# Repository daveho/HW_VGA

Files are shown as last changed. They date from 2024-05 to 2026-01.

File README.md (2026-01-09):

# Hardware VGA text mode project

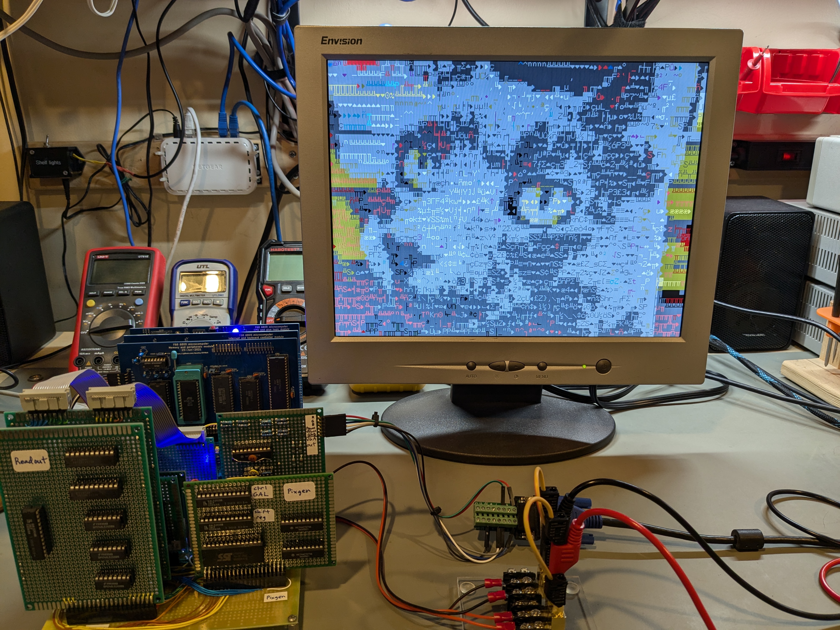
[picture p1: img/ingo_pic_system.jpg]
completed prototype showing cat picture (connected to DIY 8-bit computer)


This repository documents my (successful!) attempt to implement a VGA text mode using logic chips and GAL devices for my [8-bit computer project](https://github.com/daveho/DIY8bit).

In July 2024, the design reached the point where it was functional
as a hand-wired prototype.

In November 2025, an [FPGA implementation](https://github.com/daveho/FPGA_VGA)
of the display controller reached the point where it is fully
functional.

The project is documented as a series of youtube videos:

Video | Topic(s) | Supporting materials
----- | -------- |--------------------
[Episode 01](https://youtu.be/FBDaKUfpmKo) | Sync gen and pixel output | [Episode01](Episode01)
[Episode 02](https://youtu.be/wY-jgFELOBk) | VRAM | [Episode02](Episode02)
[Episode 03](https://youtu.be/mVbhe-eQTJc) | Readout | [Episode03](Episode03)
[Episode 04](https://youtu.be/JXyIJMKmy68) | Pixel generation | [Episode04](Episode04)
[Episode 05](https://youtu.be/PG1XWQCylTA) | FPGA implementation | [FPGA\_VGA repository](https://github.com/daveho/FPGA_VGA)

There are a few photos in the [Gallery](gallery.md).

This project was inspired by the [Wire Wrap Odyssey](https://wirewrapodyssey.com) project.

I'm using [Logisim Evolution](https://github.com/logisim-evolution/logisim-evolution) to simulate parts of the design before building the hardware.

I'm using [GALasm](https://github.com/daveho/GALasm) to compile the GAL logic equations into fuse maps. Note that even though this is hosted in my Github account, I didn't write it. (I fixed a bug and then posted the code on my Github since there didn't seem to be any existing version control repo for it.)

The [HardwareDesign](HardwareDesign) directory contains the most up-to-date hardware design. The schematics were created using (of course!) [KiCad](https://www.kicad.org/). There is a [PDF of the schematic](HardwareDesign/HW_VGA.pdf) which may or may not be up to date.

This is a work in progress! I don't make any guarantees about its usefulness or correctness. Feedback can be sent to <mailto:david.hovemeyer@gmail.com>.

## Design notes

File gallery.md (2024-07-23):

# Gallery

Here are some pictures:

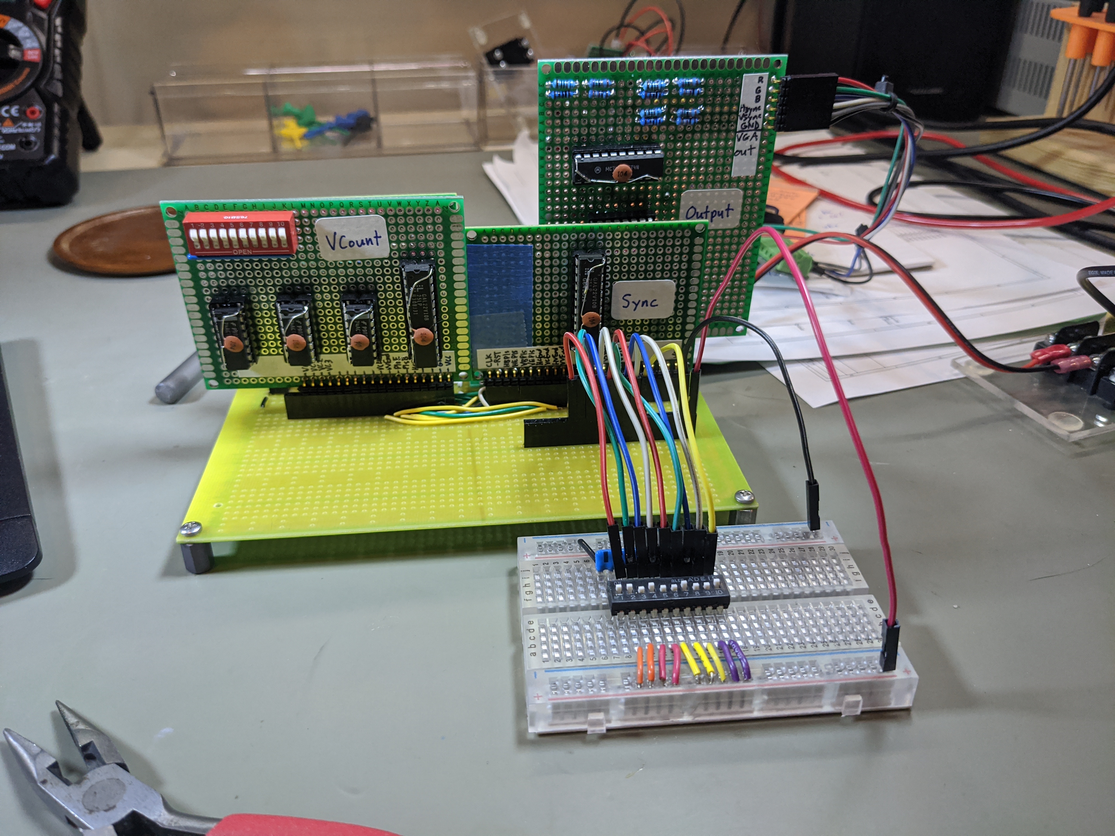
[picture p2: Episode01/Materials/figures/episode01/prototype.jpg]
photo of early prototype hardware


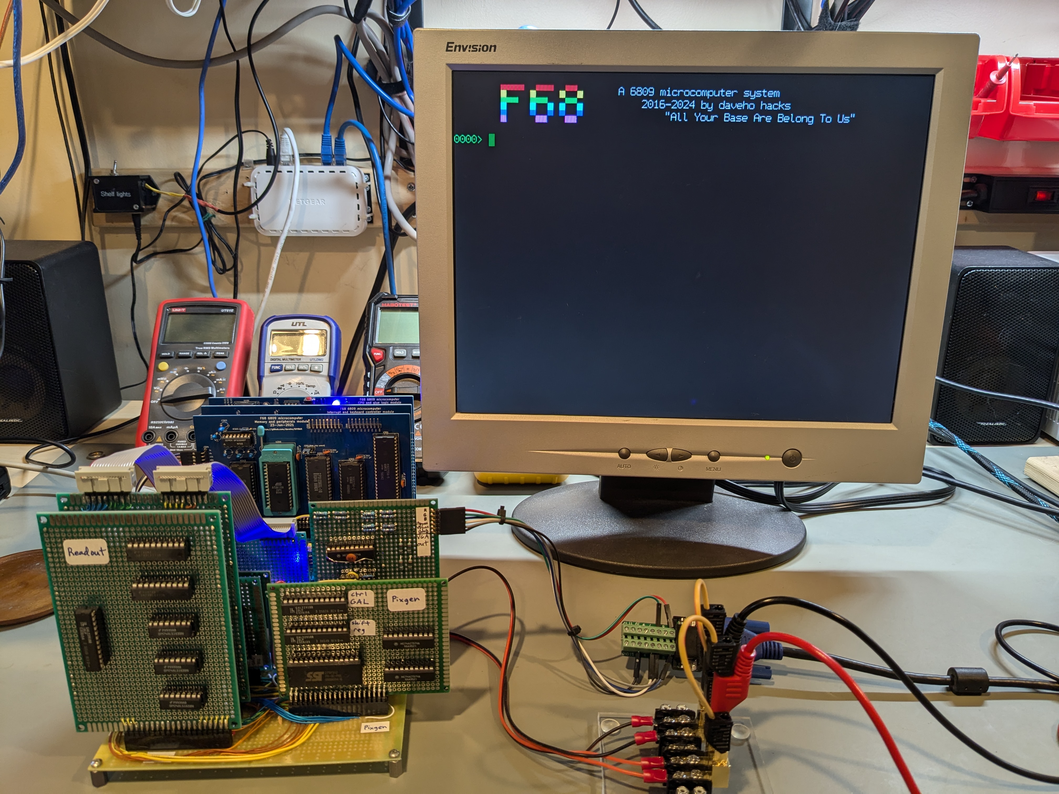
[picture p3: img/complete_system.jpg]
completed prototype (connected to DIY 8-bit computer)


completed prototype showing cat picture (connected to DIY 8-bit computer)

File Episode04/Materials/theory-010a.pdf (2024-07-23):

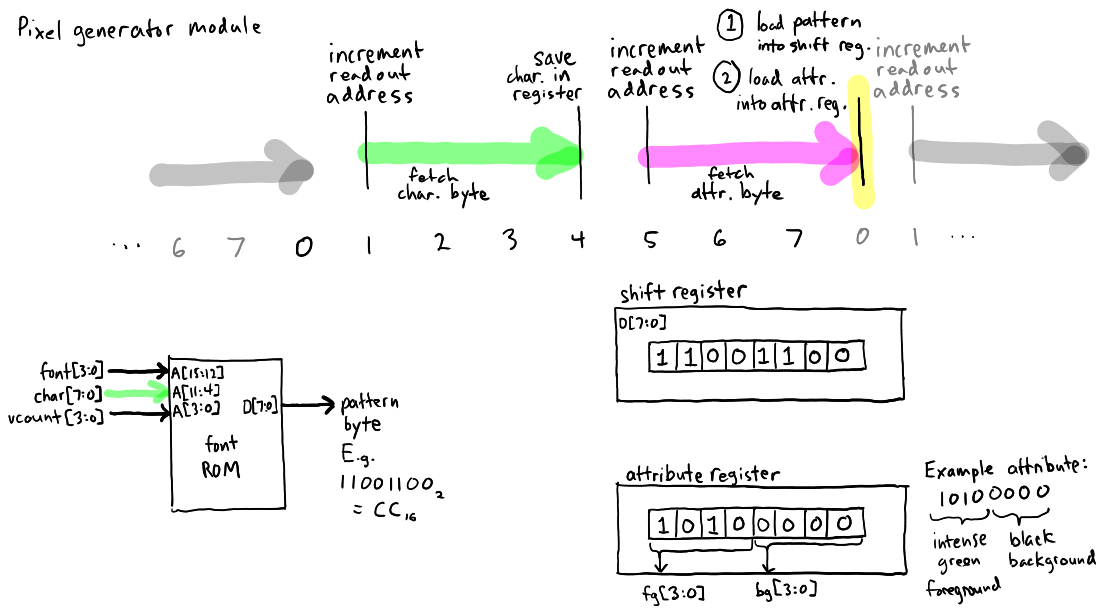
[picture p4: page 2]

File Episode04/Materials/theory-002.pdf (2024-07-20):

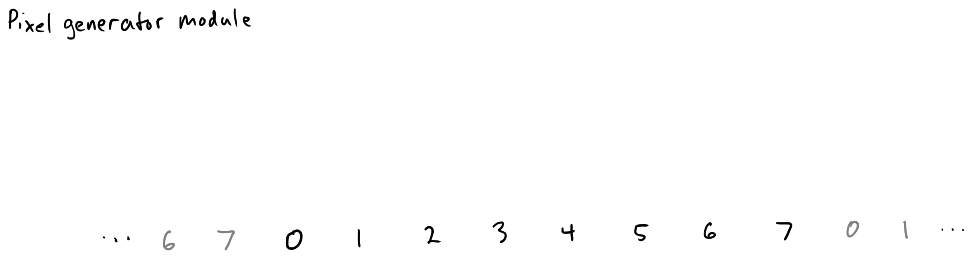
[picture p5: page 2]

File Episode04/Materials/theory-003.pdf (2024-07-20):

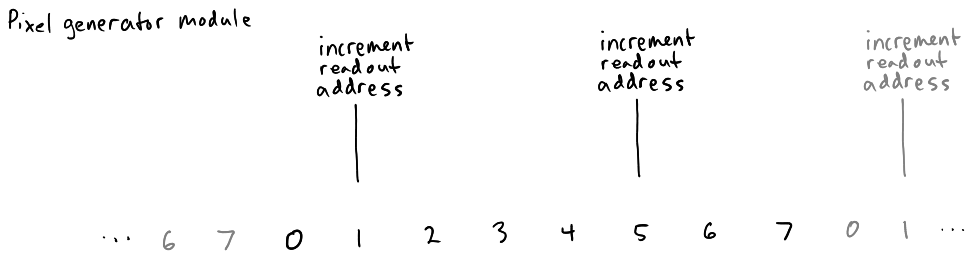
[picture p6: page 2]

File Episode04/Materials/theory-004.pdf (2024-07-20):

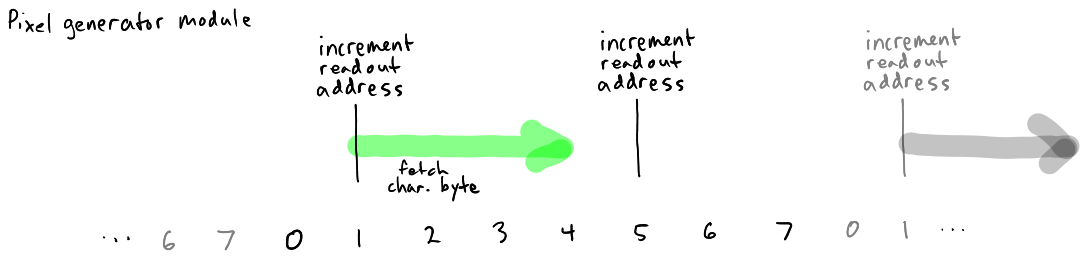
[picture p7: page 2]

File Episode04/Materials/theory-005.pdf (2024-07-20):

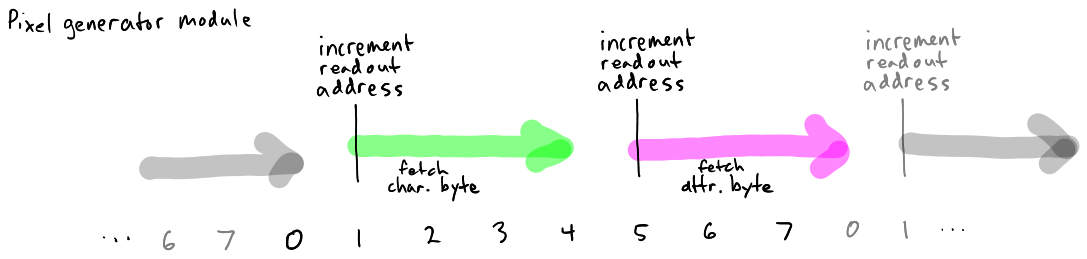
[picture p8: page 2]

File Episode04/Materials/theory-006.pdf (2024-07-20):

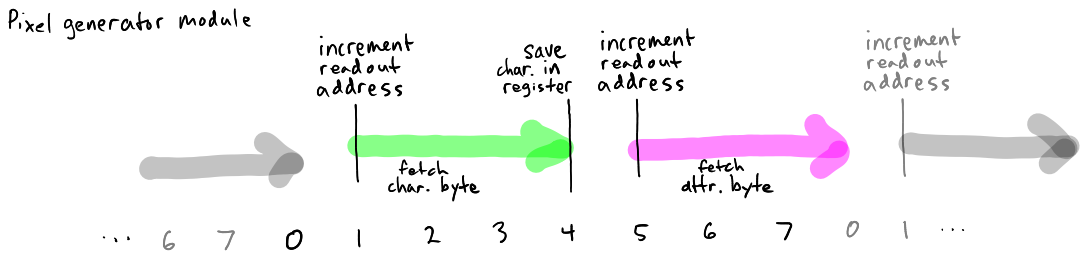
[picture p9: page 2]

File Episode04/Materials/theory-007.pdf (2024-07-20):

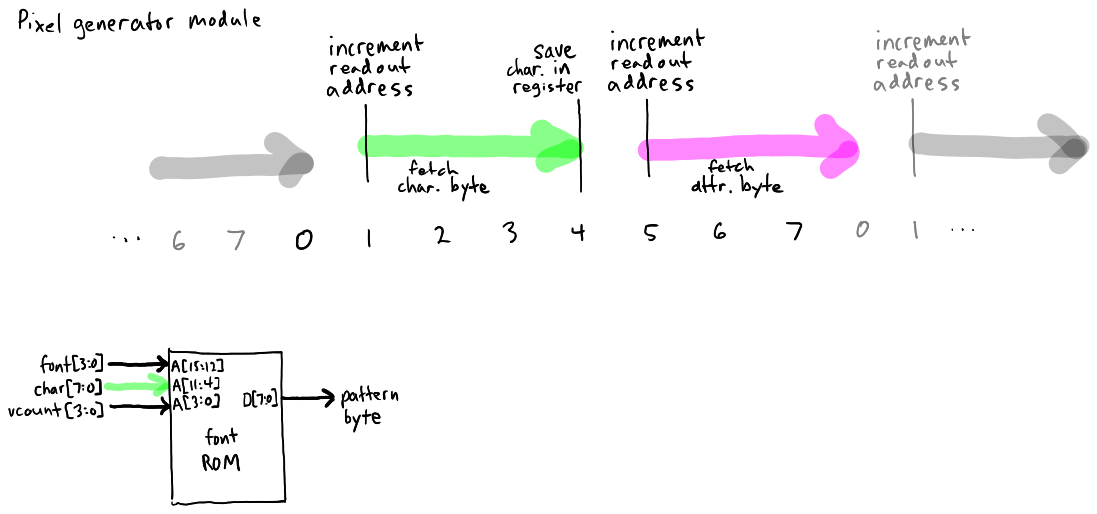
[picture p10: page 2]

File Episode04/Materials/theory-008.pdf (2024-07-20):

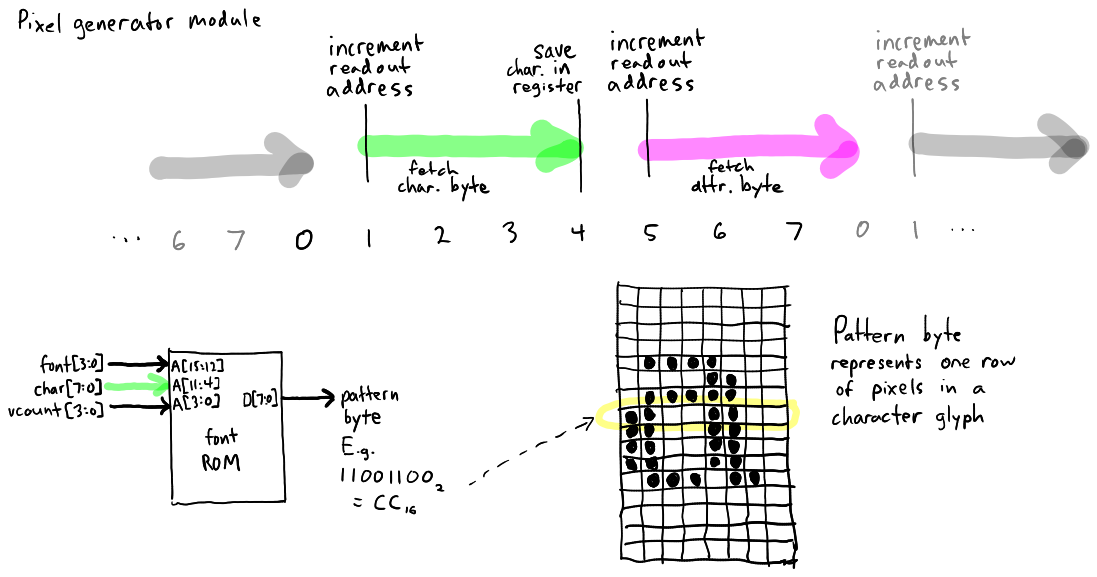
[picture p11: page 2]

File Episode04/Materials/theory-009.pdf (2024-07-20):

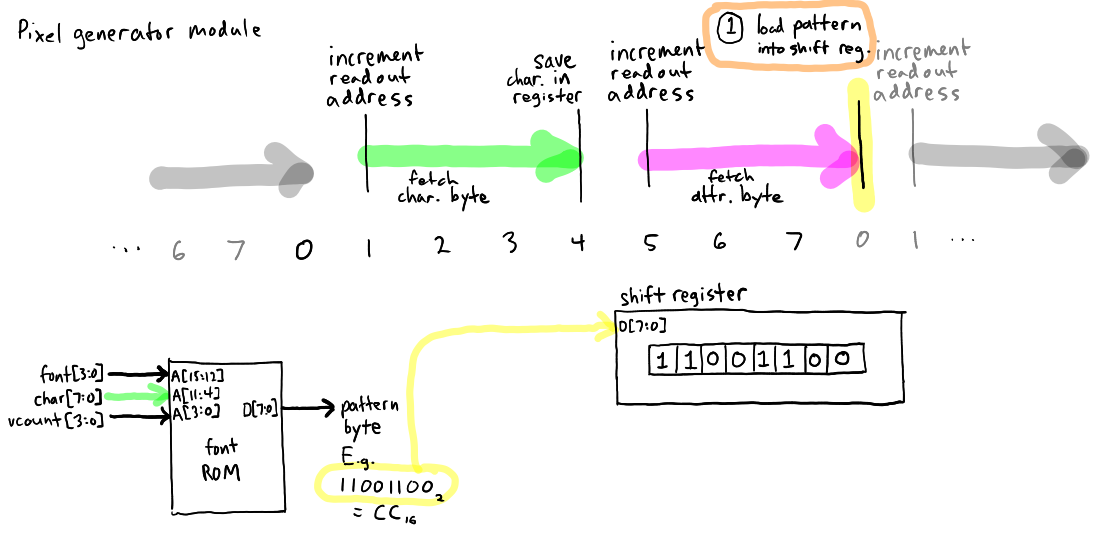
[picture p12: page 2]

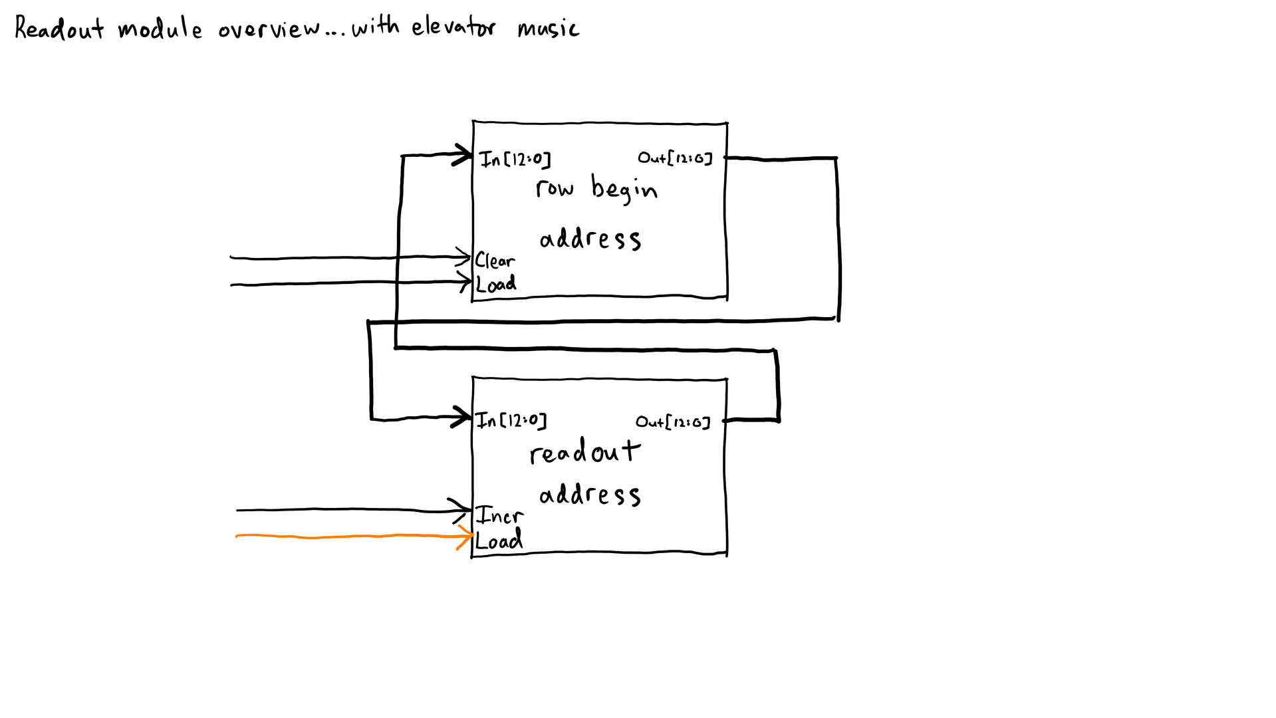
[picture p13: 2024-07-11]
Episode03/Materials/readout-overview-039.png

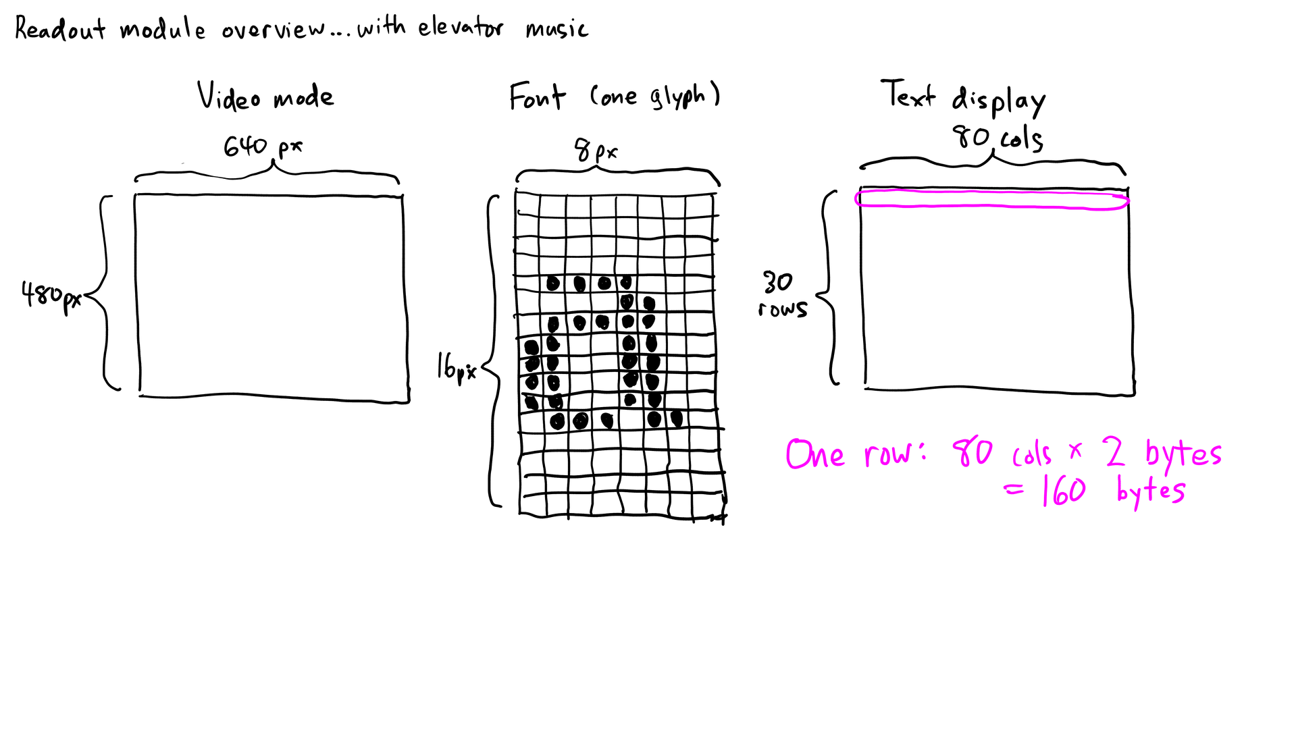
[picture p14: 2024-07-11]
Episode03/Materials/readout-overview-011.png

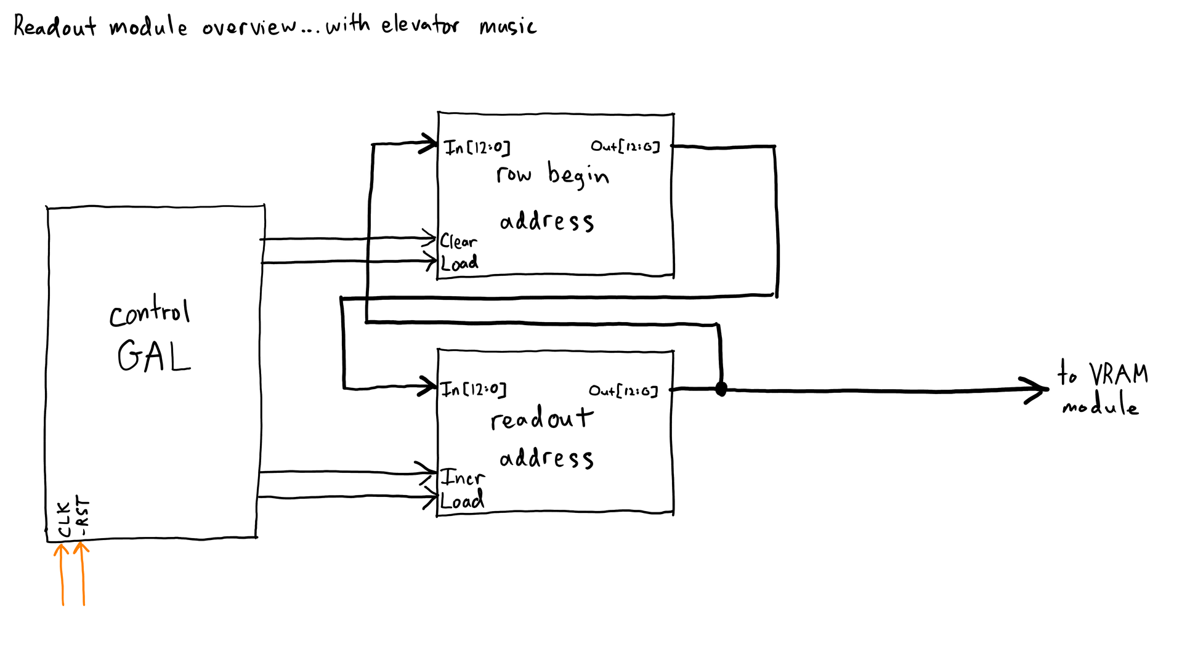
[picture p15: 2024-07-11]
Episode03/Materials/readout-overview-042.png

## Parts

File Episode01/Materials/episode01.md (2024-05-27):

---
title: "Episode 1"
aspectratio: 169
colorlinks: true
pandoc-beamer-block:
  - classes: [info]
  - classes: [alert]
    type: alert
header-includes:
  - \usepackage{graphbox}
  - \usepackage[export]{adjustbox}
  - \usepackage[absolute,overlay]{textpos}
  - \usecolortheme{orchid}
---

## 

::: { .absolute x=0.5in y=0.85in width=3in }



:::

## Hello! { .t }

New (but kind of not new) project!

## Hello! { .t }

New (but kind of not new) project!

Why no real videos for quite a while?

## Hello! { .t }

New (but kind of not new) project!

Why no real videos for quite a while?

* 8-bit computer project: initially lots of progress, lots of fun

## Hello! { .t }

New (but kind of not new) project!

Why no real videos for quite a while?

* 8-bit computer project: initially lots of progress, lots of fun
* Display controller: huge road block. Initial options:

## Hello! { .t }

New (but kind of not new) project!

Why no real videos for quite a while?

* 8-bit computer project: initially lots of progress, lots of fun
* Display controller: huge road block. Initial options:
  1. "Retro" display controller (e.g., TMS9918A)

::: { .absolute x=3in y=1.75in width=2.5in }

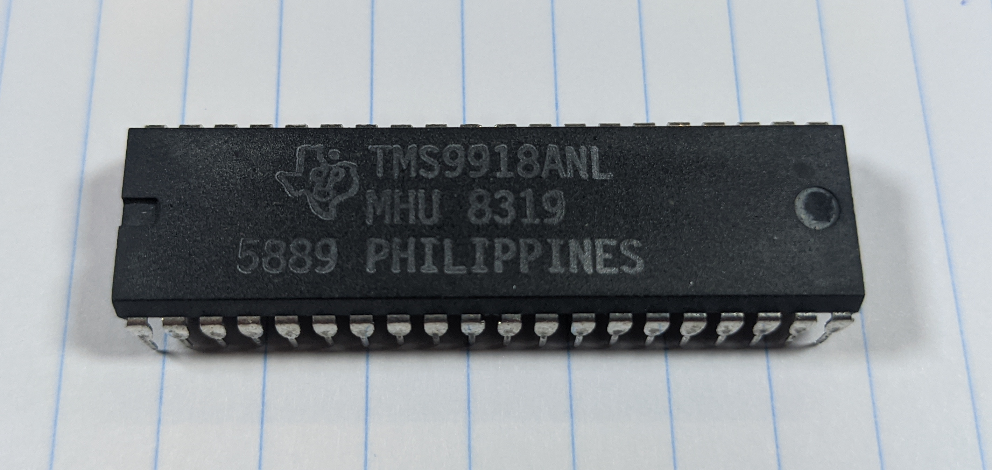
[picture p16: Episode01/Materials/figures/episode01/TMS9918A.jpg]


:::

## Hello! { .t }

New (but kind of not new) project!

Why no real videos for quite a while?

* 8-bit computer project: initially lots of progress, lots of fun
* Display controller: huge road block. Initial options:
  1. "Retro" display controller (e.g., TMS9918A)
  2. FPGA with custom design

::: { .absolute x=3in y=1.75in width=2.5in }

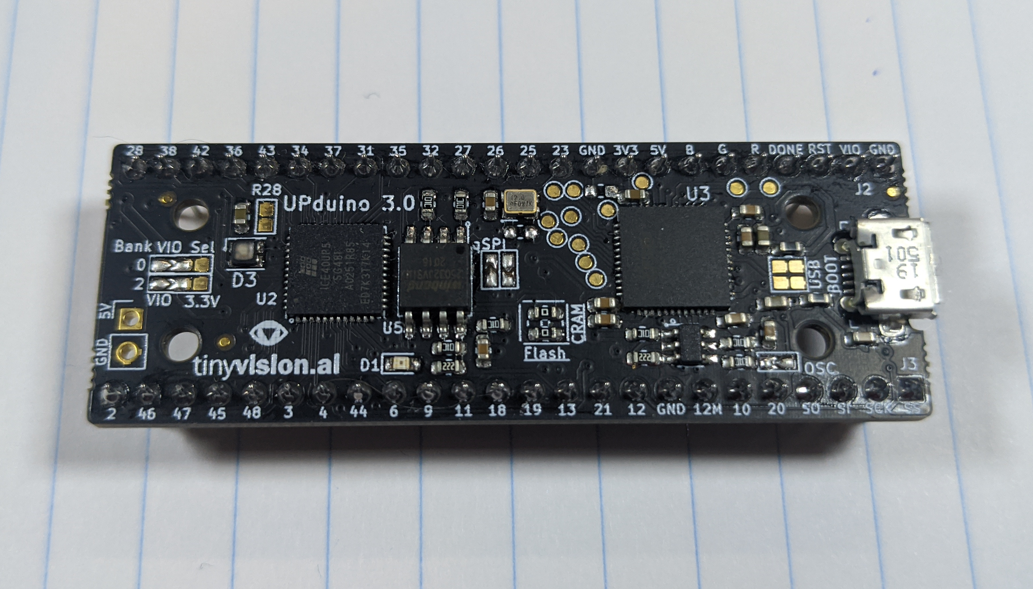
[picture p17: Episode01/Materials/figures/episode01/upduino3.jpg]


:::

## Hello! { .t }

New (but kind of not new) project!

Why no real videos for quite a while?

* 8-bit computer project: initially lots of progress, lots of fun
* Display controller: huge road block. Initial options:
  1. "Retro" display controller (e.g., TMS9918A)
  2. FPGA with custom design

Initially I thought option \#2 was best

## FPGAs are hard { .t }

Difficulties:

## FPGAs are hard { .t }

Difficulties:

* Hard to know what is going on inside the FPGA

## FPGAs are hard { .t }

Difficulties:

* Hard to know what is going on inside the FPGA
* Can't probe signals

## FPGAs are hard { .t }

Difficulties:

* Hard to know what is going on inside the FPGA
* Can't probe signals
* Need to use simulation and possibly formal verification

## FPGAs are hard { .t }

Difficulties:

* Hard to know what is going on inside the FPGA
* Can't probe signals
* Need to use simulation and possibly formal verification

My problem: I wasn't having fun!

## FPGAs are hard { .t }

Difficulties:

* Hard to know what is going on inside the FPGA
* Can't probe signals
* Need to use simulation and possibly formal verification

My problem: I wasn't having fun!

* I like building things

## FPGAs are hard { .t }

Difficulties:

* Hard to know what is going on inside the FPGA
* Can't probe signals
* Need to use simulation and possibly formal verification

My problem: I wasn't having fun!

* I like building things
* I like debugging circuits (using multimeter, oscilloscope, etc.)

## What about option \#1? { .t }

I did experiment with the TMS9918A with some success:

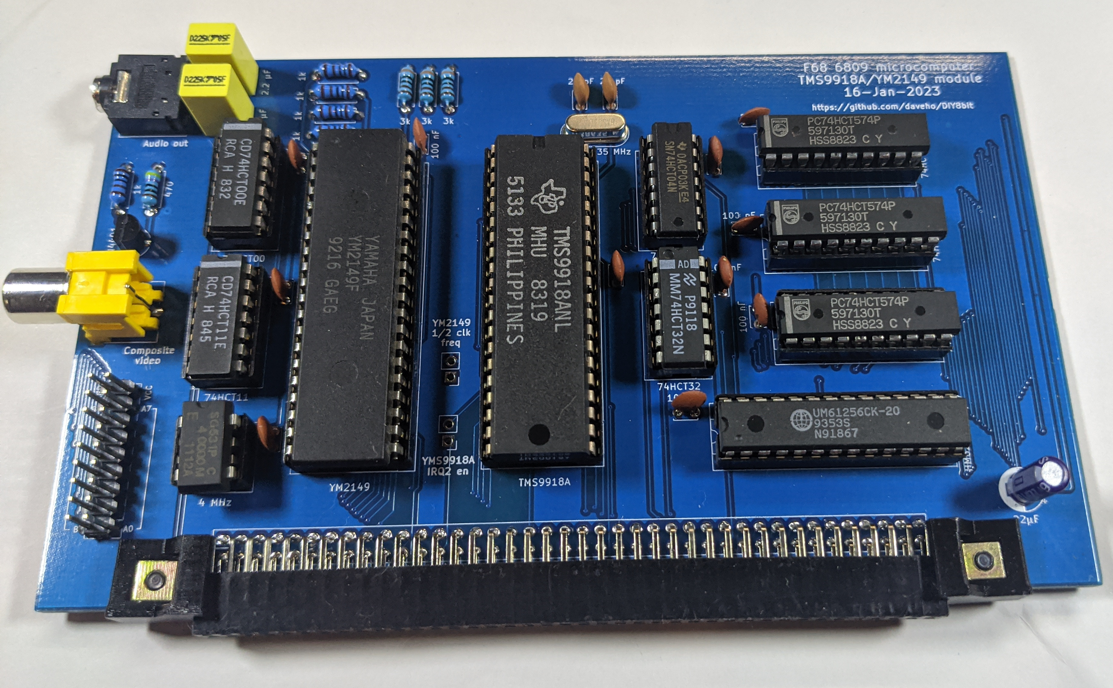
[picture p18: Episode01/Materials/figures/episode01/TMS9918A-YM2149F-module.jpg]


I will return to this at some point

## What to do? { .t }

Was feeling very unmotivated: option \#1 unsatisfactory, option \#2 not fun

## What to do? { .t }

Was feeling very unmotivated: option \#1 unsatisfactory, option \#2 not fun

**What if there was a third option?**

## What to do? { .t }

Was feeling very unmotivated: option \#1 unsatisfactory, option \#2 not fun

**What if there was a third option?**

Wire Wrap Odyssey project (<https://wirewrapodyssey.com>)

VGA text display implemented using logic chips!

::: { .absolute x=2.75in y=1.625in width=3in }

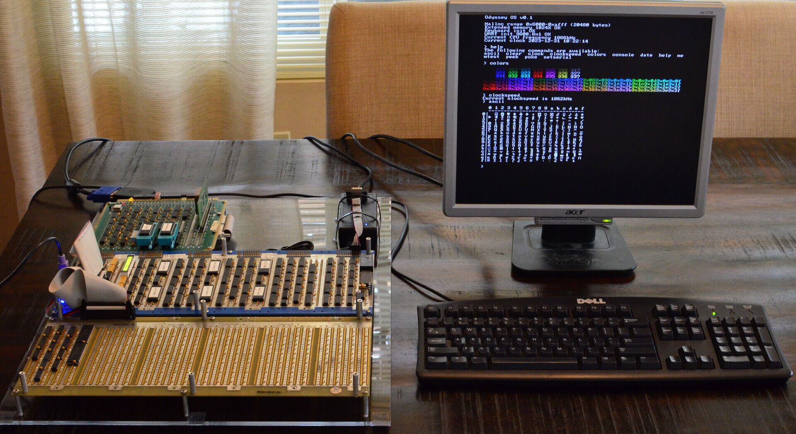
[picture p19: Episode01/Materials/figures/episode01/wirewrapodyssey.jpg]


:::

## What to do? { .t }

Was feeling very unmotivated: option \#1 unsatisfactory, option \#2 not fun

**What if there was a third option?**

Wire Wrap Odyssey project (<https://wirewrapodyssey.com>)

VGA text display implemented using logic chips!

::: { .absolute x=2.75in y=1.625in width=3in }



:::

``` {=latex}
\vskip .1in
\hspace{.2in}\fbox{\parbox{1.5in}{
\Large Could I do\\
something similar?
}}
```

## Why VGA text mode using logic chips? { .t }

## Why VGA text mode using logic chips? { .t }

1. Fun!

## Why VGA text mode using logic chips? { .t }

1. Fun!
2. Use actual hardware!

## Why VGA text mode using logic chips? { .t }

1. Fun!
2. Use actual hardware!
3. Direct access to signals

## Why VGA text mode using logic chips? { .t }

1. Fun!
2. Use actual hardware!
3. Direct access to signals
4. Modular design $\rightarrow$ build and test incrementally

## Why VGA text mode using logic chips? { .t }

1. Fun!
2. Use actual hardware!
3. Direct access to signals
4. Modular design $\rightarrow$ build and test incrementally

There are challenges...

## Why VGA text mode using logic chips? { .t }

1. Fun!
2. Use actual hardware!
3. Direct access to signals
4. Modular design $\rightarrow$ build and test incrementally

There are challenges...

`\hspace{.25in}`{=latex} ...but I think they can be managed

## Challenge \#1: Hardware Complexity { .t }

## Challenge \#1: Hardware Complexity { .t }

Problem: design could require a large number of logic chips

## Challenge \#1: Hardware Complexity { .t }

Problem: design could require a large number of logic chips

Solution: use programmable logic!

## Challenge \#1: Hardware Complexity { .t }

Problem: design could require a large number of logic chips

Solution: use programmable logic!

Wait, didn't you say that programmable logic wasn't fun?

## Challenge \#1: Hardware Complexity { .t }

Problem: design could require a large number of logic chips

Solution: use programmable logic!

Wait, didn't you say that programmable logic wasn't fun?

GAL devices! (e.g., GAL22V10)

::: { .absolute x=4.25in y=1in width=2in }

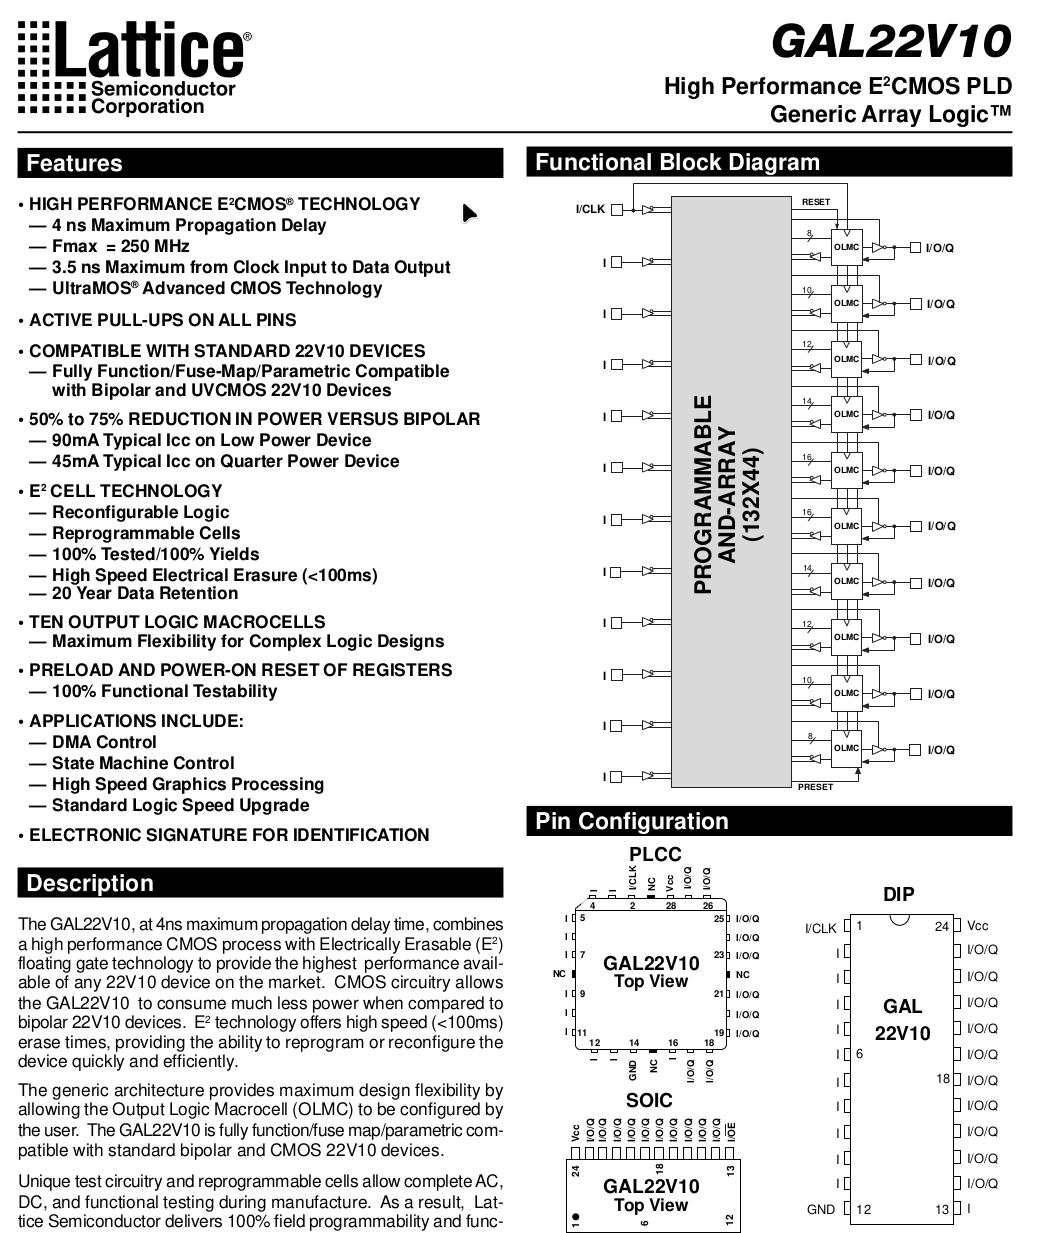
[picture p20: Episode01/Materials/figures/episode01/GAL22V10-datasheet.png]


:::

::: { .absolute x=4in y=1.5in width=2in }

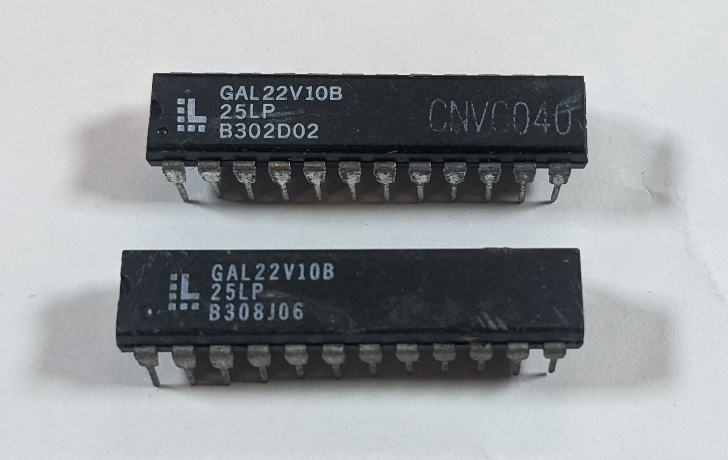
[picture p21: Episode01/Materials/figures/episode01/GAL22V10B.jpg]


:::

## Challenge \#1: Hardware Complexity { .t }

Problem: design could require a large number of logic chips

Solution: use programmable logic!

Wait, didn't you say that programmable logic wasn't fun?

GAL devices! (e.g., GAL22V10)

* Can replace multiple discrete chips

::: { .absolute x=4.25in y=1in width=2in }



:::

::: { .absolute x=4in y=1.5in width=2in }



:::

## Challenge \#1: Hardware Complexity { .t }

Problem: design could require a large number of logic chips

Solution: use programmable logic!

Wait, didn't you say that programmable logic wasn't fun?

GAL devices! (e.g., GAL22V10)

* Can replace multiple discrete chips
* Easy to source (EBay, etc.)

::: { .absolute x=4.25in y=1in width=2in }



:::

::: { .absolute x=4in y=1.5in width=2in }



:::

## Challenge \#1: Hardware Complexity { .t }

Problem: design could require a large number of logic chips

Solution: use programmable logic!

Wait, didn't you say that programmable logic wasn't fun?

GAL devices! (e.g., GAL22V10)

* Can replace multiple discrete chips
* Easy to source (EBay, etc.)
* Atmel has compatible parts still in  
  production!

::: { .absolute x=4.25in y=1in width=2in }



:::

::: { .absolute x=3.75in y=1.5in width=2.5in }

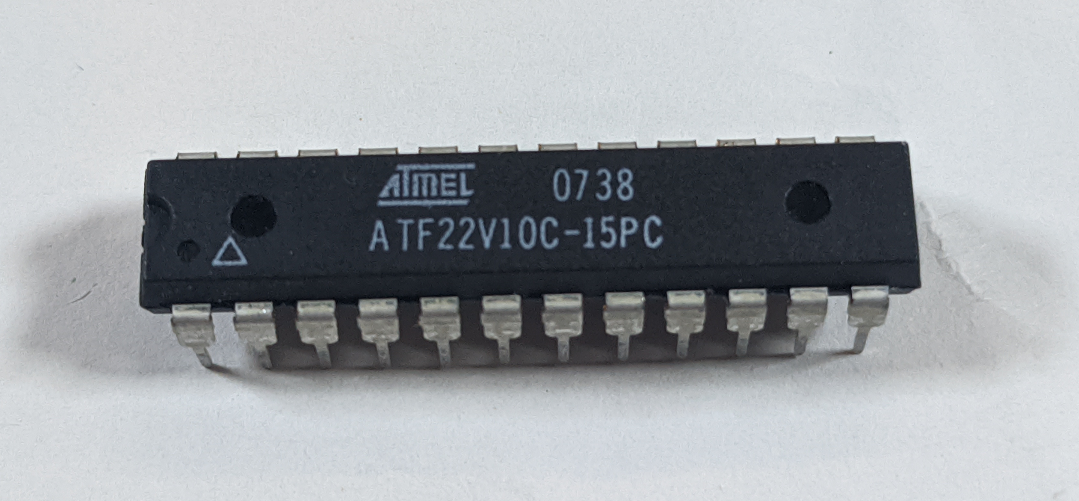
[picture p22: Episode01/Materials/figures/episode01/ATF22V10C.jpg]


:::

## Challenge \#1: Hardware Complexity { .t }

Problem: design could require a large number of logic chips

Solution: use programmable logic!

Wait, didn't you say that programmable logic wasn't fun?

GAL devices! (e.g., GAL22V10)

* Can replace multiple discrete chips
* Easy to source (EBay, etc.)
* Atmel has compatible parts still in  
  production!
* Easily programmed

::: { .absolute x=4.25in y=1in width=2in }



:::

::: { .absolute x=3.75in y=1.5in width=2.5in }



:::

## Challenge \#1: Hardware Complexity { .t }

Problem: design could require a large number of logic chips

Solution: use programmable logic!

Wait, didn't you say that programmable logic wasn't fun?

GAL devices! (e.g., GAL22V10)

* Can replace multiple discrete chips
* Easy to source (EBay, etc.)
* Atmel has compatible parts still in  
  production!
* Easily programmed
* Fast enough for 640x480 VGA

::: { .absolute x=4.25in y=1in width=2in }



:::

::: { .absolute x=3.75in y=1.5in width=2.5in }



:::

## Challenge \#1: Hardware Complexity { .t }

Problem: design could require a large number of logic chips

Solution: use programmable logic!

Wait, didn't you say that programmable logic wasn't fun?

GAL devices! (e.g., GAL22V10)

* Can replace multiple discrete chips
* Easy to source (EBay, etc.)
* Atmel has compatible parts still in  
  production!
* Easily programmed
* Fast enough for 640x480 VGA
* Have pins you can probe directly!

::: { .absolute x=4.25in y=1in width=2in }



:::

::: { .absolute x=3.75in y=1.5in width=2.5in }



:::

## Challenge \#1: Hardware Complexity { .t }

Problem: design could require a large number of logic chips

Solution: use programmable logic!

Wait, didn't you say that programmable logic wasn't fun?

GAL devices! (e.g., GAL22V10)

* Can replace multiple discrete chips
* Easy to source (EBay, etc.)
* Atmel has compatible parts still in  
  production!
* Easily programmed
* Fast enough for 640x480 VGA
* Have pins you can probe directly!
* Reprogrammable: fix bugs easily

::: { .absolute x=4.25in y=1in width=2in }



:::

::: { .absolute x=3.75in y=1.5in width=2.5in }



:::

## Challenge \#2: Design Complexity { .t }

## Challenge \#2: Design Complexity { .t }

Problems:

## Challenge \#2: Design Complexity { .t }

Problems:

* With $25.175$ MHz clock, need to generate a pixel every $39.7$ ns

## Challenge \#2: Design Complexity { .t }

Problems:

* With $25.175$ MHz clock, need to generate a pixel every $39.7$ ns
* Logic to fetch data from VRAM and rasterize it will be intricate

## Challenge \#2: Design Complexity { .t }

Problems:

* With $25.175$ MHz clock, need to generate a pixel every $39.7$ ns
* Logic to fetch data from VRAM and rasterize it will be intricate
* Will be important to validate design before implementing

## Challenge \#2: Design Complexity { .t }

Problems:

* With $25.175$ MHz clock, need to generate a pixel every $39.7$ ns
* Logic to fetch data from VRAM and rasterize it will be intricate
* Will be important to validate design before implementing

Solution: simulation using Logisim Evolution

## Challenge \#2: Design Complexity { .t }

Problems:

* With $25.175$ MHz clock, need to generate a pixel every $39.7$ ns
* Logic to fetch data from VRAM and rasterize it will be intricate
* Will be important to validate design before implementing

Solution: simulation using Logisim Evolution

* Simulate design before building it

## Challenge \#2: Design Complexity { .t }

Problems:

* With $25.175$ MHz clock, need to generate a pixel every $39.7$ ns
* Logic to fetch data from VRAM and rasterize it will be intricate
* Will be important to validate design before implementing

Solution: simulation using Logisim Evolution

* Simulate design before building it
* Includes 74 series devices in library (e.g., 74x163 counter)

## Challenge \#2: Design Complexity { .t }

Problems:

* With $25.175$ MHz clock, need to generate a pixel every $39.7$ ns
* Logic to fetch data from VRAM and rasterize it will be intricate
* Will be important to validate design before implementing

Solution: simulation using Logisim Evolution

* Simulate design before building it
* Includes 74 series devices in library (e.g., 74x163 counter)
* GALs can easily be modeled using combinational logic and
  D-type flip flops

## Challenge \#3: High Frequency { .t }

## Challenge \#3: High Frequency { .t }

Problem: dot clock is $25.175$ MHz

## Challenge \#3: High Frequency { .t }

Problem: dot clock is $25.175$ MHz

* 74HC and 74HCT series chips can't operate reliably!

## Challenge \#3: High Frequency { .t }

Problem: dot clock is $25.175$ MHz

* 74HC and 74HCT series chips can't operate reliably!
* I have limited experience with implementing designs at this frequency

## Challenge \#3: High Frequency { .t }

Problem: dot clock is $25.175$ MHz

* 74HC and 74HCT series chips can't operate reliably!
* I have limited experience with implementing designs at this frequency

Solution: 74ACT series, GALs

## Challenge \#3: High Frequency { .t }

Problem: dot clock is $25.175$ MHz

* 74HC and 74HCT series chips can't operate reliably!
* I have limited experience with implementing designs at this frequency

Solution: 74ACT series, GALs

* 74ACT chips: can operate up to 125 MHz or so

## Challenge \#3: High Frequency { .t }

Problem: dot clock is $25.175$ MHz

* 74HC and 74HCT series chips can't operate reliably!
* I have limited experience with implementing designs at this frequency

Solution: 74ACT series, GALs

* 74ACT chips: can operate up to 125 MHz or so
* GALs can also operate at high frequency, so can use them
  for any functions where a 74ACT chip isn't readily available

## Challenge \#3: High Frequency { .t }

Problem: dot clock is $25.175$ MHz

* 74HC and 74HCT series chips can't operate reliably!
* I have limited experience with implementing designs at this frequency

Solution: 74ACT series, GALs

* 74ACT chips: can operate up to 125 MHz or so
* GALs can also operate at high frequency, so can use them
  for any functions where a 74ACT chip isn't readily available

Some initial high-speed parts of the design are already working!

## Challenge \#4: Video Memory { .t }

## Challenge \#4: Video Memory { .t }

Problem: how to allow host system and display controller to
share access to VRAM?

## Challenge \#4: Video Memory { .t }

Problem: how to allow host system and display controller to
share access to VRAM?

* Could time-share: complex, possibly detrimental for performance

## Challenge \#4: Video Memory { .t }

Problem: how to allow host system and display controller to
share access to VRAM?

* Could time-share: complex, possibly detrimental for performance

Solution: dual-port static RAM

## Challenge \#4: Video Memory { .t }

Problem: how to allow host system and display controller to
share access to VRAM?

* Could time-share: complex, possibly detrimental for performance

Solution: dual-port static RAM

* Specifically 2 $\times$ IDT7134 for a total  
  of 8 KB VRAM

::: { .absolute x=3.5in y=1.5in width=2.5in }

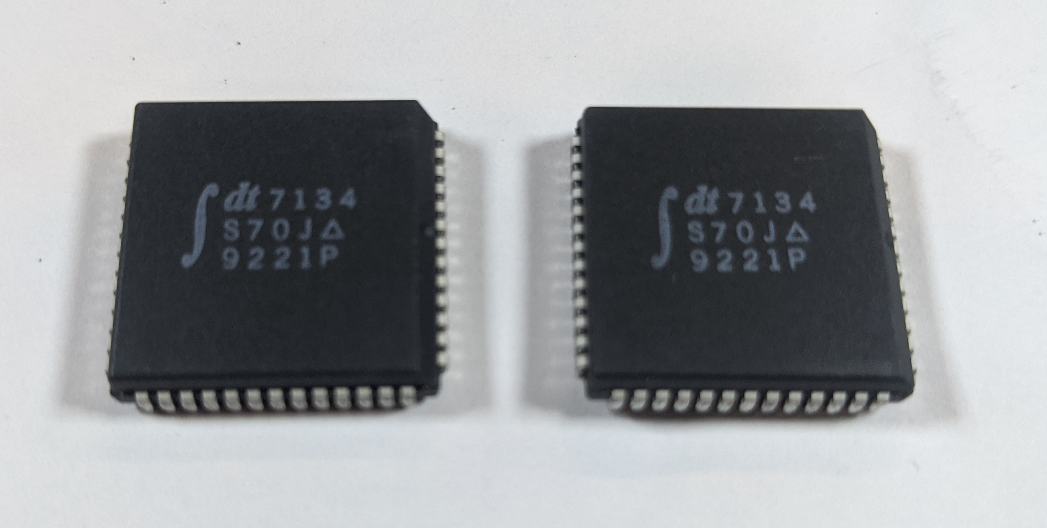
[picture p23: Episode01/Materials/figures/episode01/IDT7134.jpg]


:::

## Challenge \#4: Video Memory { .t }

Problem: how to allow host system and display controller to
share access to VRAM?

* Could time-share: complex, possibly detrimental for performance

Solution: dual-port static RAM

* Specifically 2 $\times$ IDT7134 for a total  
  of 8 KB VRAM
* Display controller can read while host  
  system  is reading or writing

::: { .absolute x=3.5in y=1.5in width=2.5in }



:::

## Challenge \#4: Video Memory { .t }

Problem: how to allow host system and display controller to
share access to VRAM?

* Could time-share: complex, possibly detrimental for performance

Solution: dual-port static RAM

* Specifically 2 $\times$ IDT7134 for a total  
  of 8 KB VRAM
* Display controller can read while host  
  system  is reading or writing
* Map into host system address space using  
  2 KB  of  4 KB I/O area

::: { .absolute x=3.5in y=1.5in width=2.5in }



:::

## Challenge \#4: Video Memory { .t }

Problem: how to allow host system and display controller to
share access to VRAM?

* Could time-share: complex, possibly detrimental for performance

Solution: dual-port static RAM

* Specifically 2 $\times$ IDT7134 for a total  
  of 8 KB VRAM
* Display controller can read while host  
  system  is reading or writing
* Map into host system address space using  
  2 KB  of  4 KB I/O area
  * Have a writable register to select a  
    2 KB bank

::: { .absolute x=3.5in y=1.5in width=2.5in }



:::

## Challenge \#5: Rendering Pipeline { .t }

## Challenge \#5: Rendering Pipeline { .t }

Problem: need to fetch character and attribute data, look up
font data, and deliver to pixel output hardware *exactly* when
needed

## Challenge \#5: Rendering Pipeline { .t }

Problem: need to fetch character and attribute data, look up
font data, and deliver to pixel output hardware *exactly* when
needed

* Timing of control signals will need to be very precise

## Challenge \#5: Rendering Pipeline { .t }

Problem: need to fetch character and attribute data, look up
font data, and deliver to pixel output hardware *exactly* when
needed

* Timing of control signals will need to be very precise

IDT7134 chips have access time of 70 ns or better, so 2 clock
cycles

## Challenge \#5: Rendering Pipeline { .t }

Problem: need to fetch character and attribute data, look up
font data, and deliver to pixel output hardware *exactly* when
needed

* Timing of control signals will need to be very precise

IDT7134 chips have access time of 70 ns or better, so 2 clock
cycles

This will be the most challenging part of the design!

## Challenge \#6: Physical Size { .t }

## Challenge \#6: Physical Size { .t }

Problem: cards are 15 cm $\times$ 9 cm in size

## Challenge \#6: Physical Size { .t }

Problem: cards are 15 cm $\times$ 9 cm in size

* Design will likely require quite a few chips

## Challenge \#6: Physical Size { .t }

Problem: cards are 15 cm $\times$ 9 cm in size

* Design will likely require quite a few chips
* Using through-hole parts, might not fit!

## Challenge \#6: Physical Size { .t }

Problem: cards are 15 cm $\times$ 9 cm in size

* Design will likely require quite a few chips
* Using through-hole parts, might not fit!

Solution: use surface mount parts

## Challenge \#6: Physical Size { .t }

Problem: cards are 15 cm $\times$ 9 cm in size

* Design will likely require quite a few chips
* Using through-hole parts, might not fit!

Solution: use surface mount parts

* Should be able to fit quite a few SOIC footprint parts on one card

## Challenge \#6: Physical Size { .t }

Problem: cards are 15 cm $\times$ 9 cm in size

* Design will likely require quite a few chips
* Using through-hole parts, might not fit!

Solution: use surface mount parts

* Should be able to fit quite a few SOIC footprint parts on one card
* Will probably leave VRAM and GALs as through-hole so they
  can be socketed

## Challenge \#7: Time and Effort { .t }

Problem: this project will take some time

## Challenge \#7: Time and Effort { .t }

Problem: this project will take some time

Solution: I should have some time!

## Challenge \#7: Time and Effort { .t }

Problem: this project will take some time

Solution: I should have some time!

* No accreditation self study report

::: { .absolute x=4in y=1.5in width=1.25in }



:::

## Challenge \#7: Time and Effort { .t }

Problem: this project will take some time

Solution: I should have some time!

* No accreditation self study report
* No new Zelda or DLC

::: { .absolute x=3.75in y=0.75in width=1.75in }



:::

## Challenge \#7: Time and Effort { .t }

Problem: this project will take some time

Solution: I should have some time!

* No accreditation self study report
* No new Zelda or DLC
* I'm excited about working on this!

::: { .absolute x=3.25in y=1in width=2.75in }



:::

## Getting Started... { .t }

## Getting Started... { .t }

Initial goals:

## Getting Started... { .t }

Initial goals:

* Generate horizontal and vertical sync signals

## Getting Started... { .t }

Initial goals:

* Generate horizontal and vertical sync signals
* Generate pixel visibility

## Getting Started... { .t }

Initial goals:

* Generate horizontal and vertical sync signals
* Generate pixel visibility
* Implement sync and color output

## Getting Started... { .t }

Initial goals:

* Generate horizontal and vertical sync signals
* Generate pixel visibility
* Implement sync and color output

This should allow us to display a solid foreground or background
color on a VGA monitor

## Getting Started... { .t }

Initial goals:

* Generate horizontal and vertical sync signals
* Generate pixel visibility
* Implement sync and color output

This should allow us to display a solid foreground or background
color on a VGA monitor

Might not sound too exciting, but this is a fairly substantial
part of the overall problem

## Getting Started... { .t }

Initial goals:

* Generate horizontal and vertical sync signals
* Generate pixel visibility
* Implement sync and color output

This should allow us to display a solid foreground or background
color on a VGA monitor

Might not sound too exciting, but this is a fairly substantial
part of the overall problem

* Timing of sync signals can be leveraged for other internal
  control signals

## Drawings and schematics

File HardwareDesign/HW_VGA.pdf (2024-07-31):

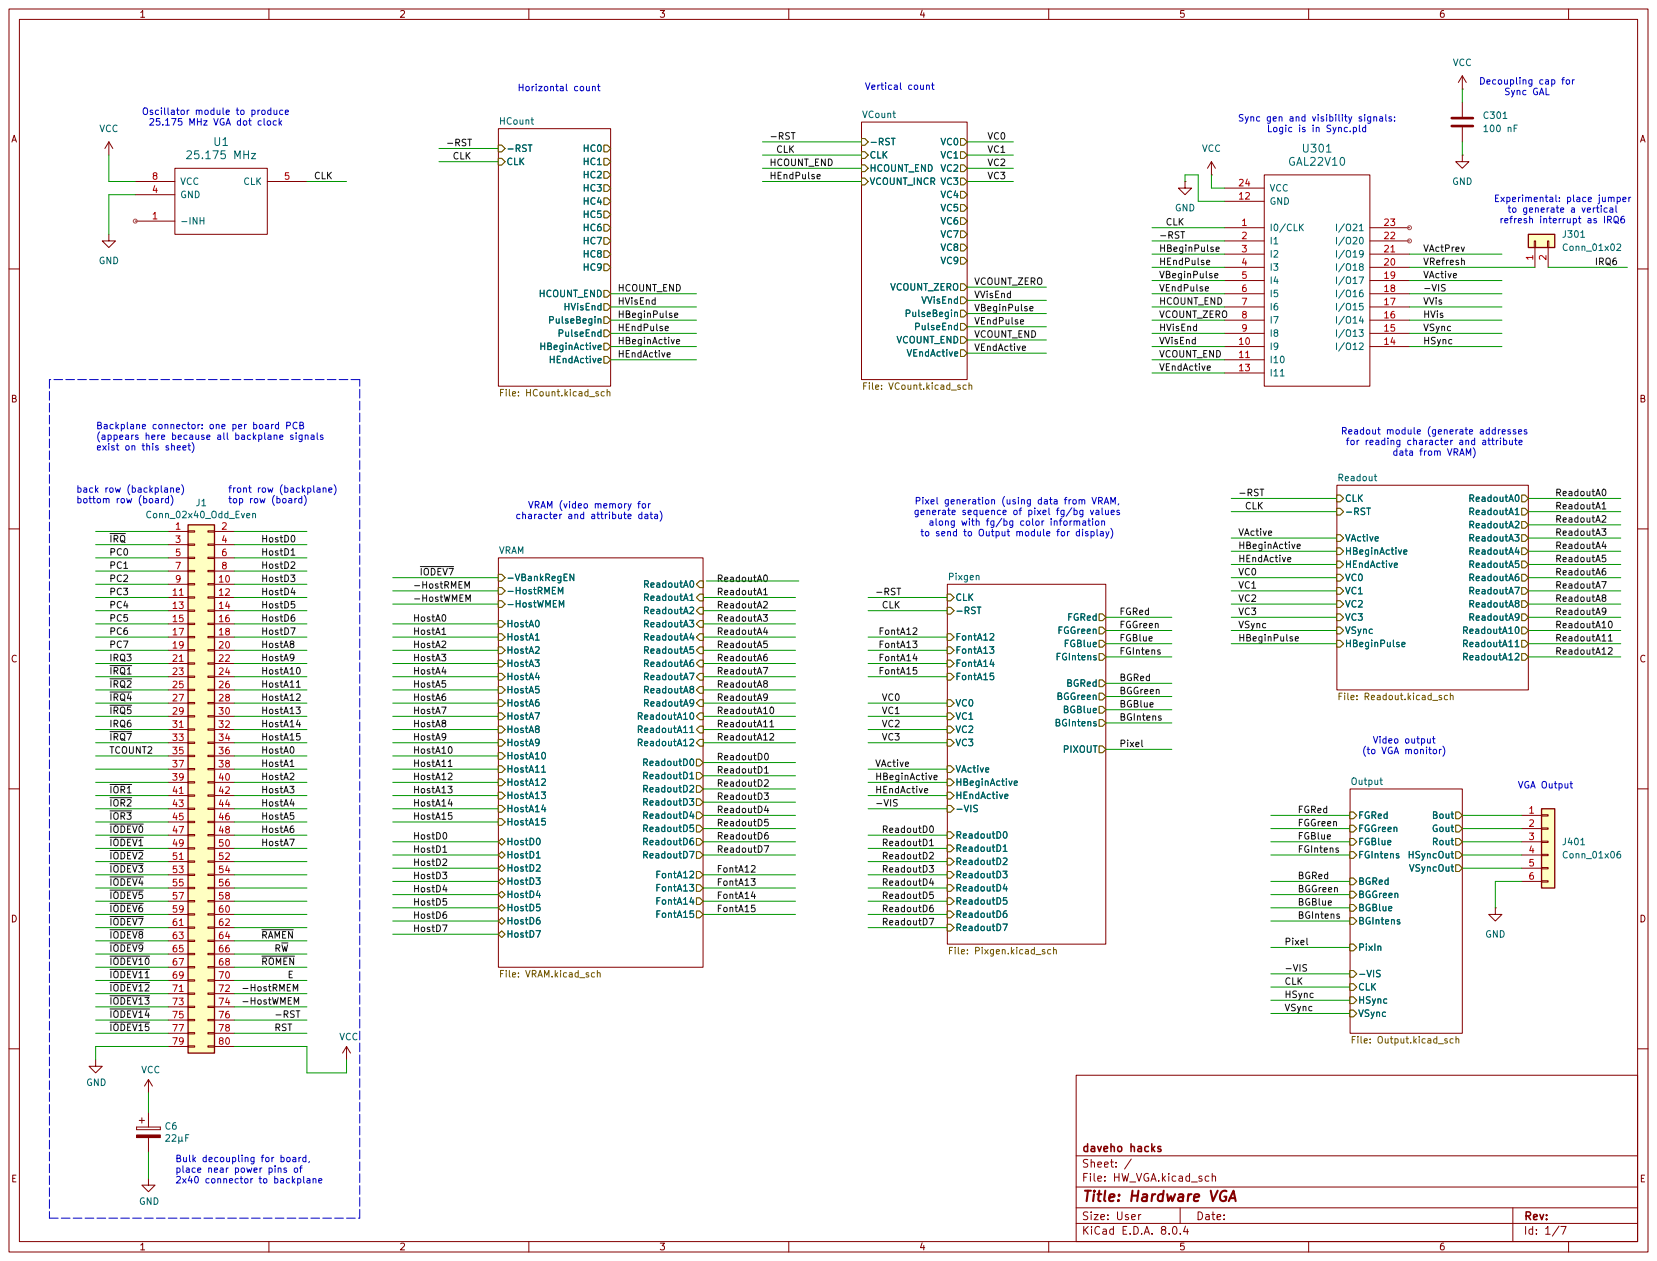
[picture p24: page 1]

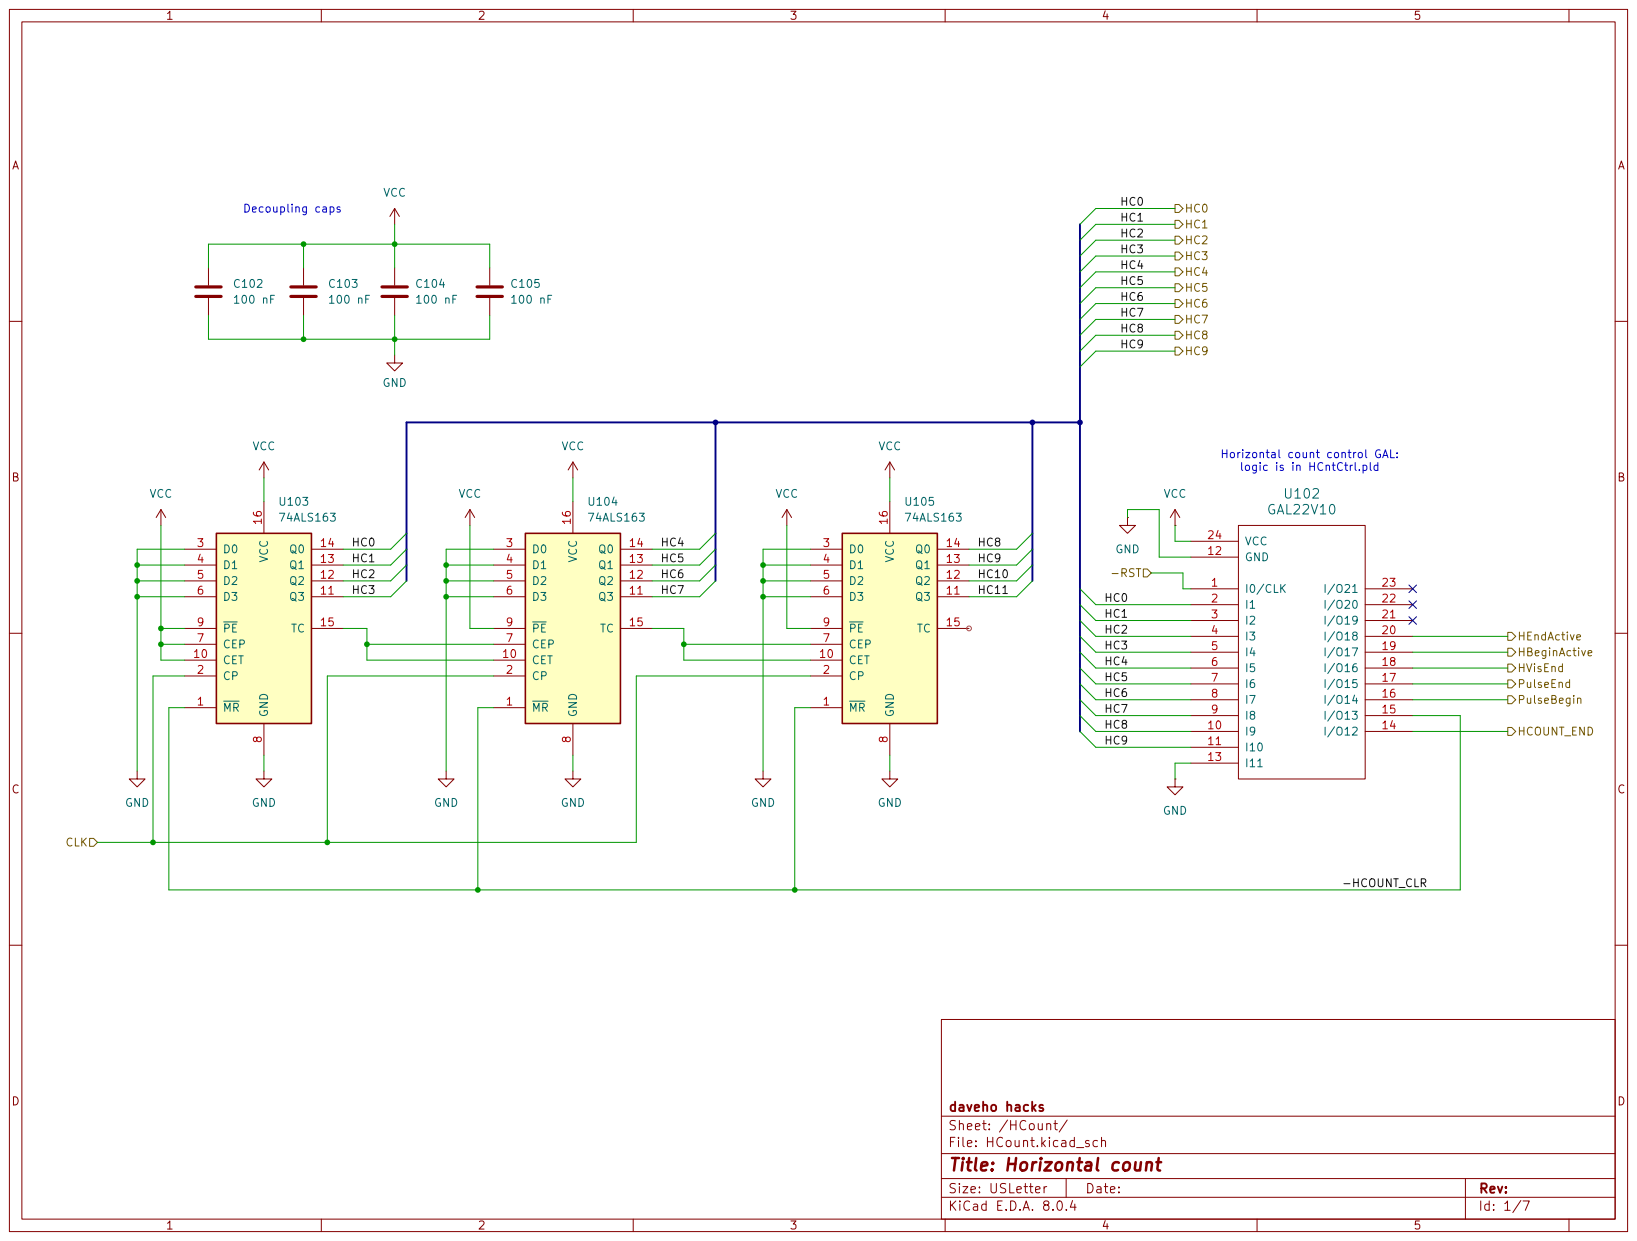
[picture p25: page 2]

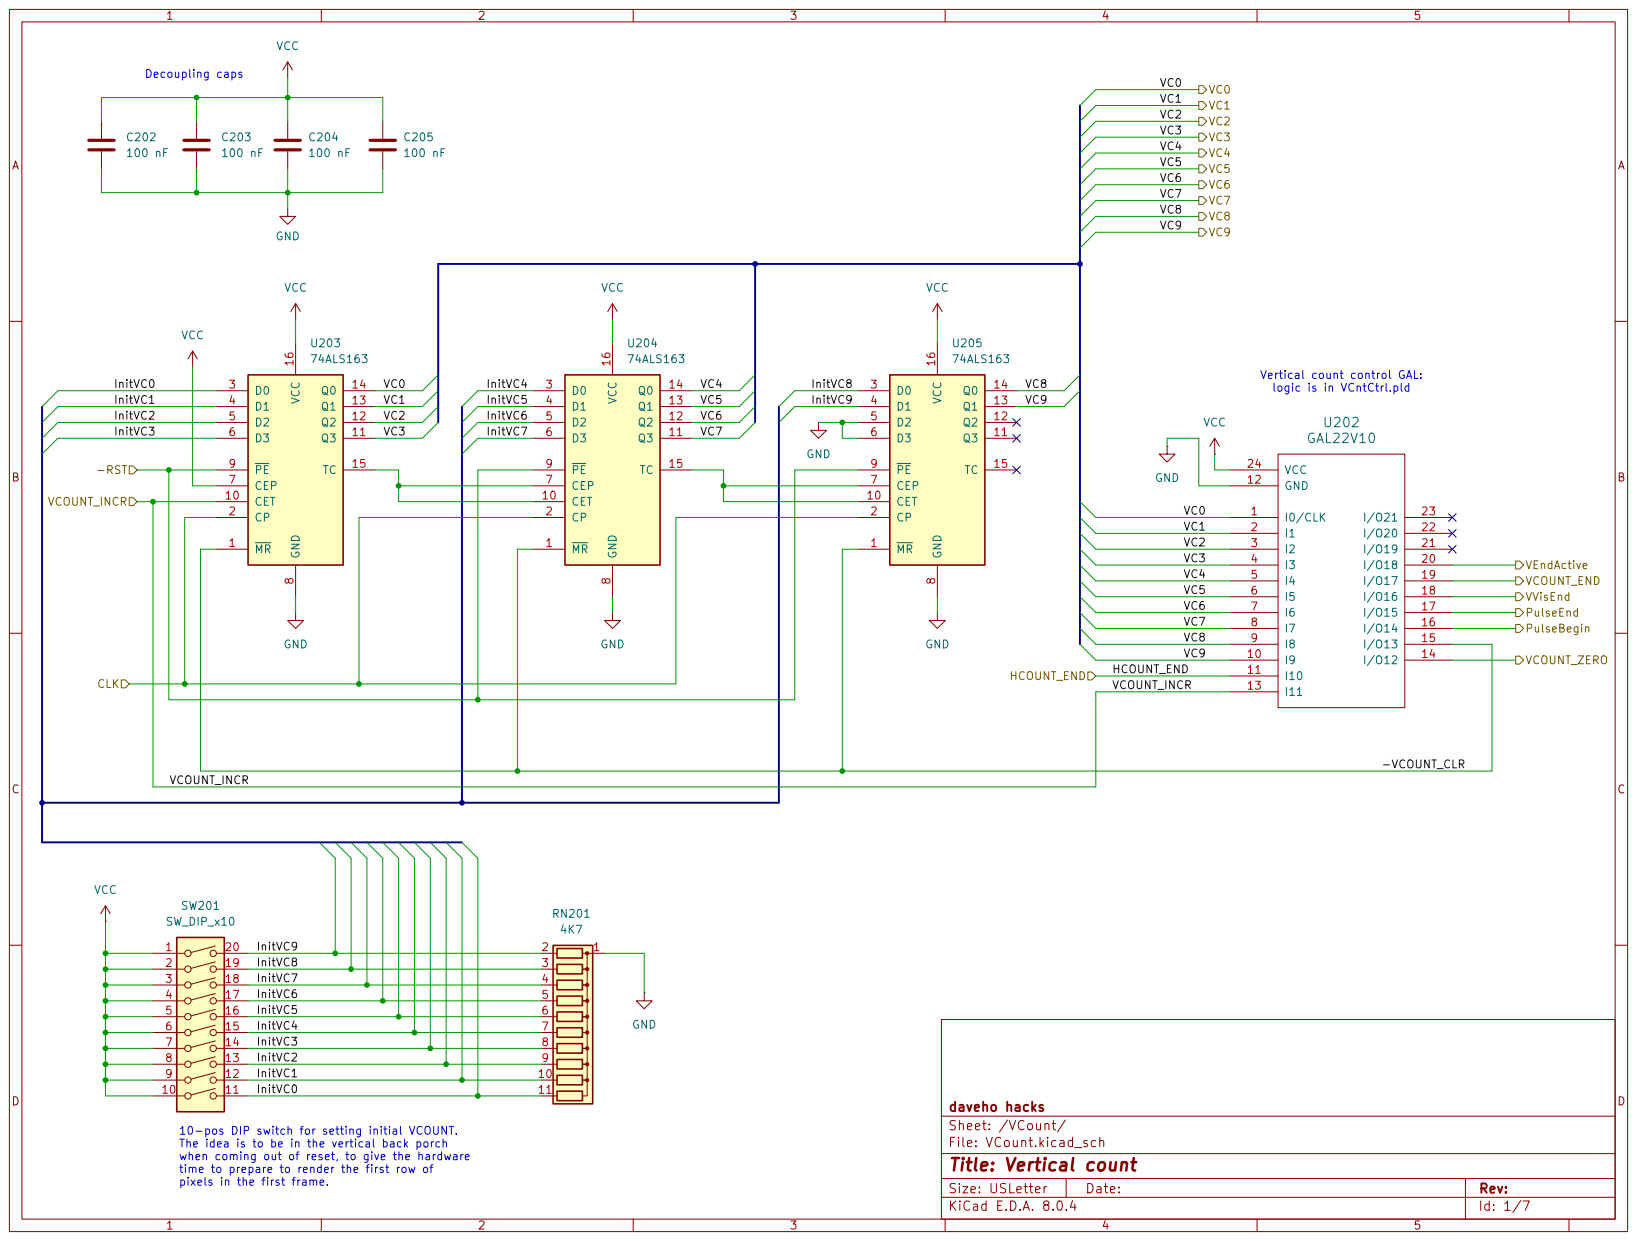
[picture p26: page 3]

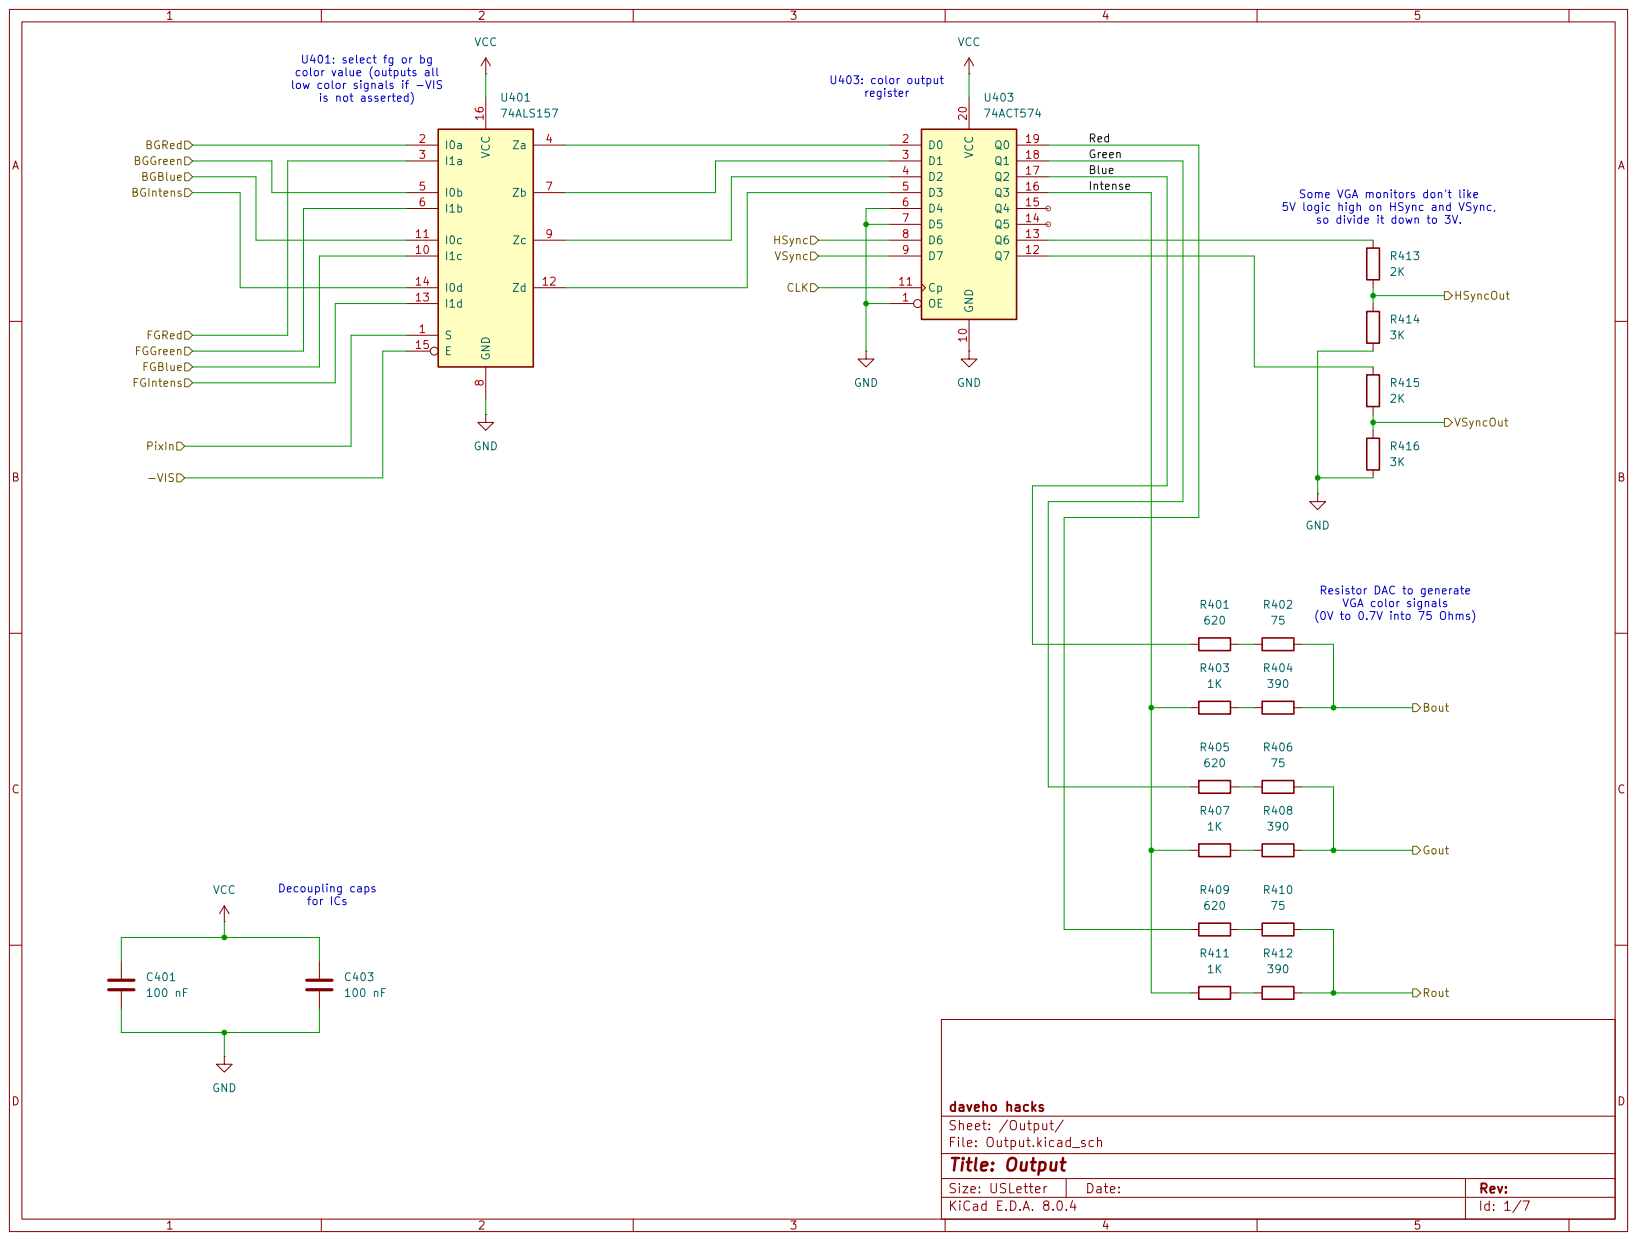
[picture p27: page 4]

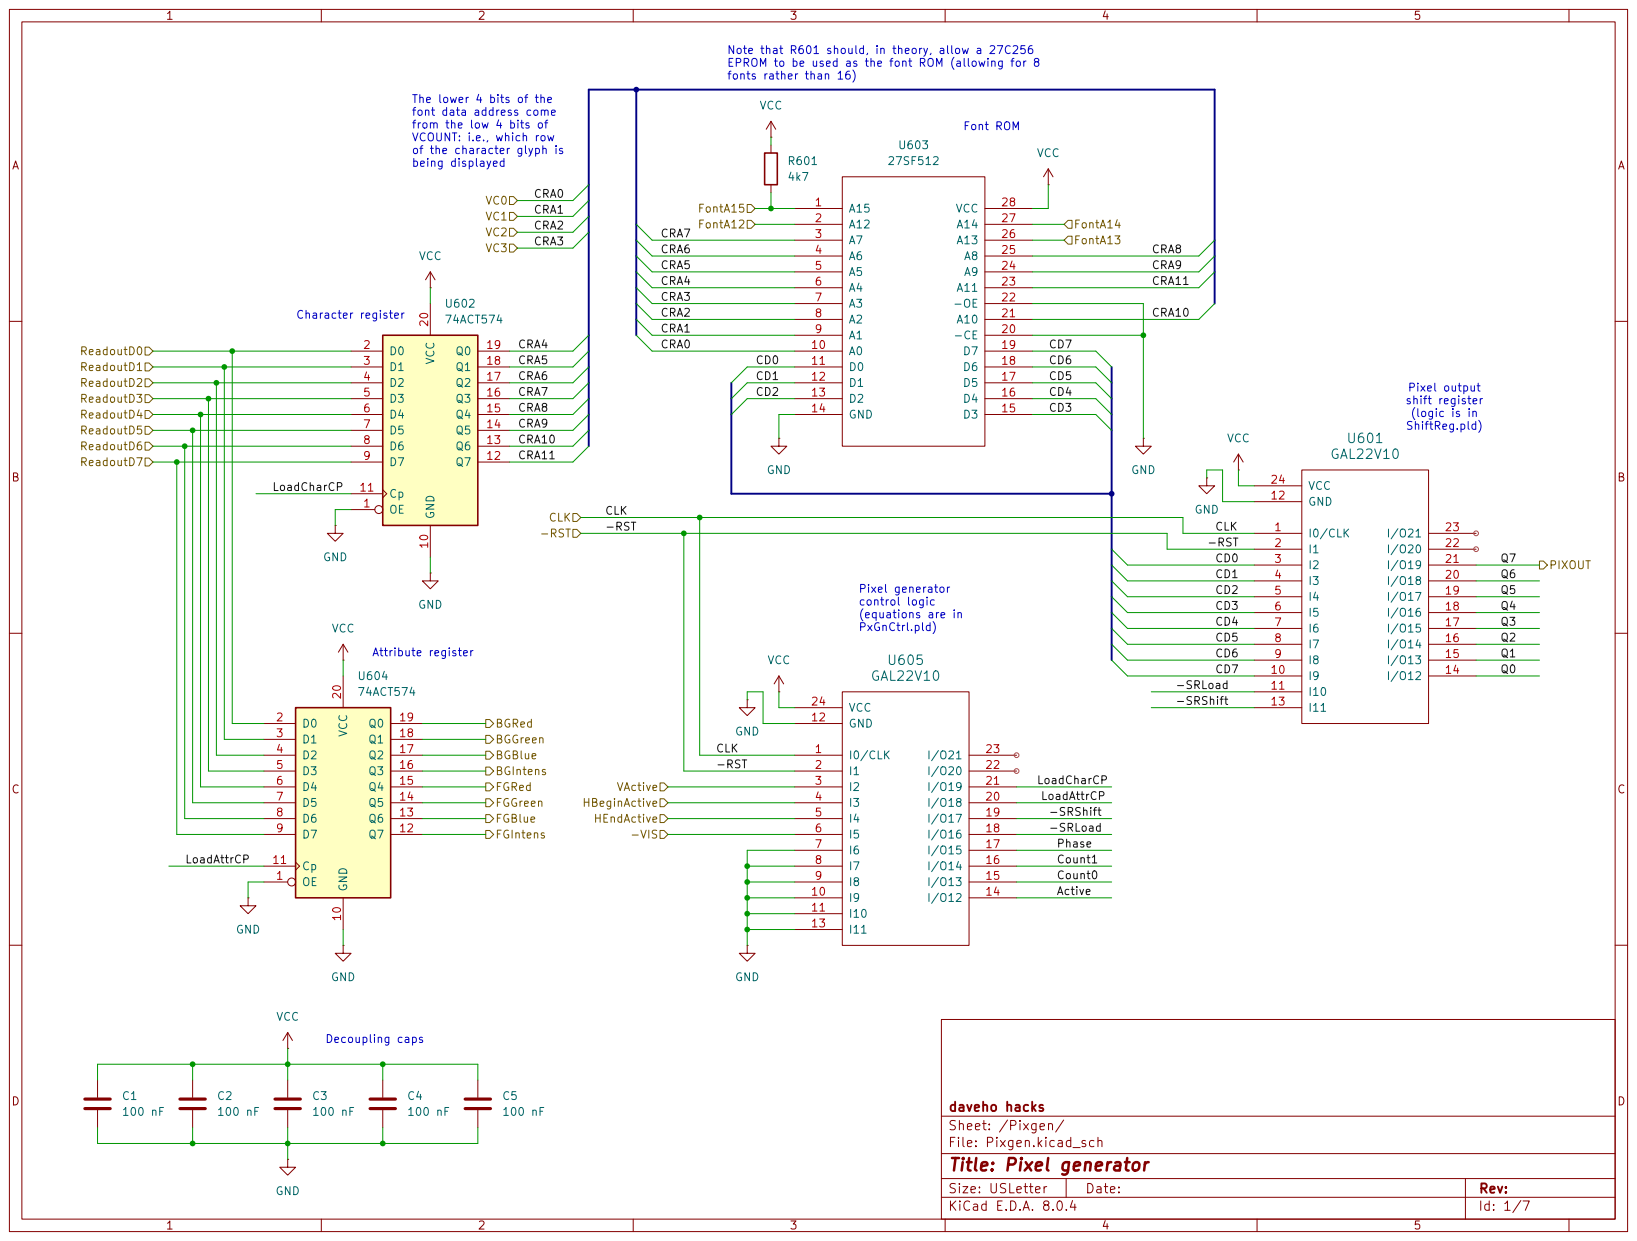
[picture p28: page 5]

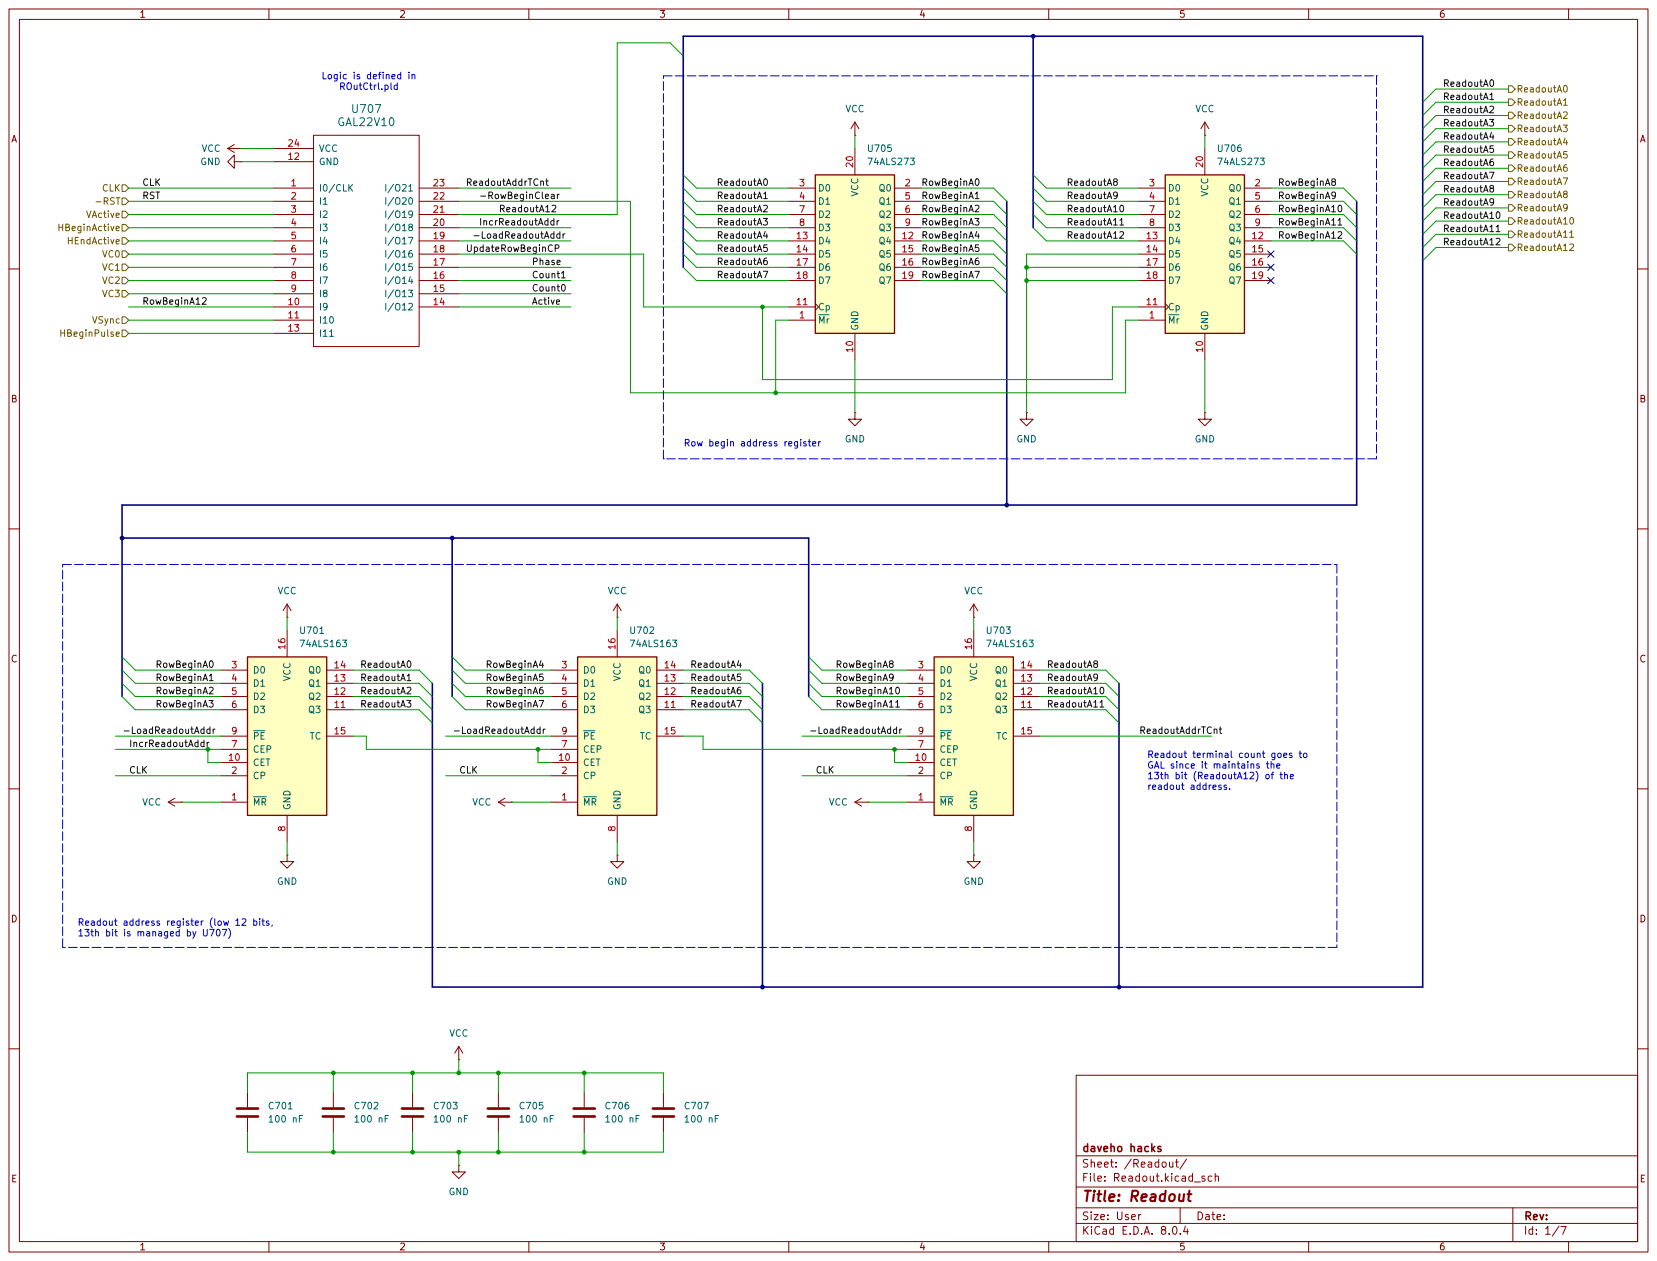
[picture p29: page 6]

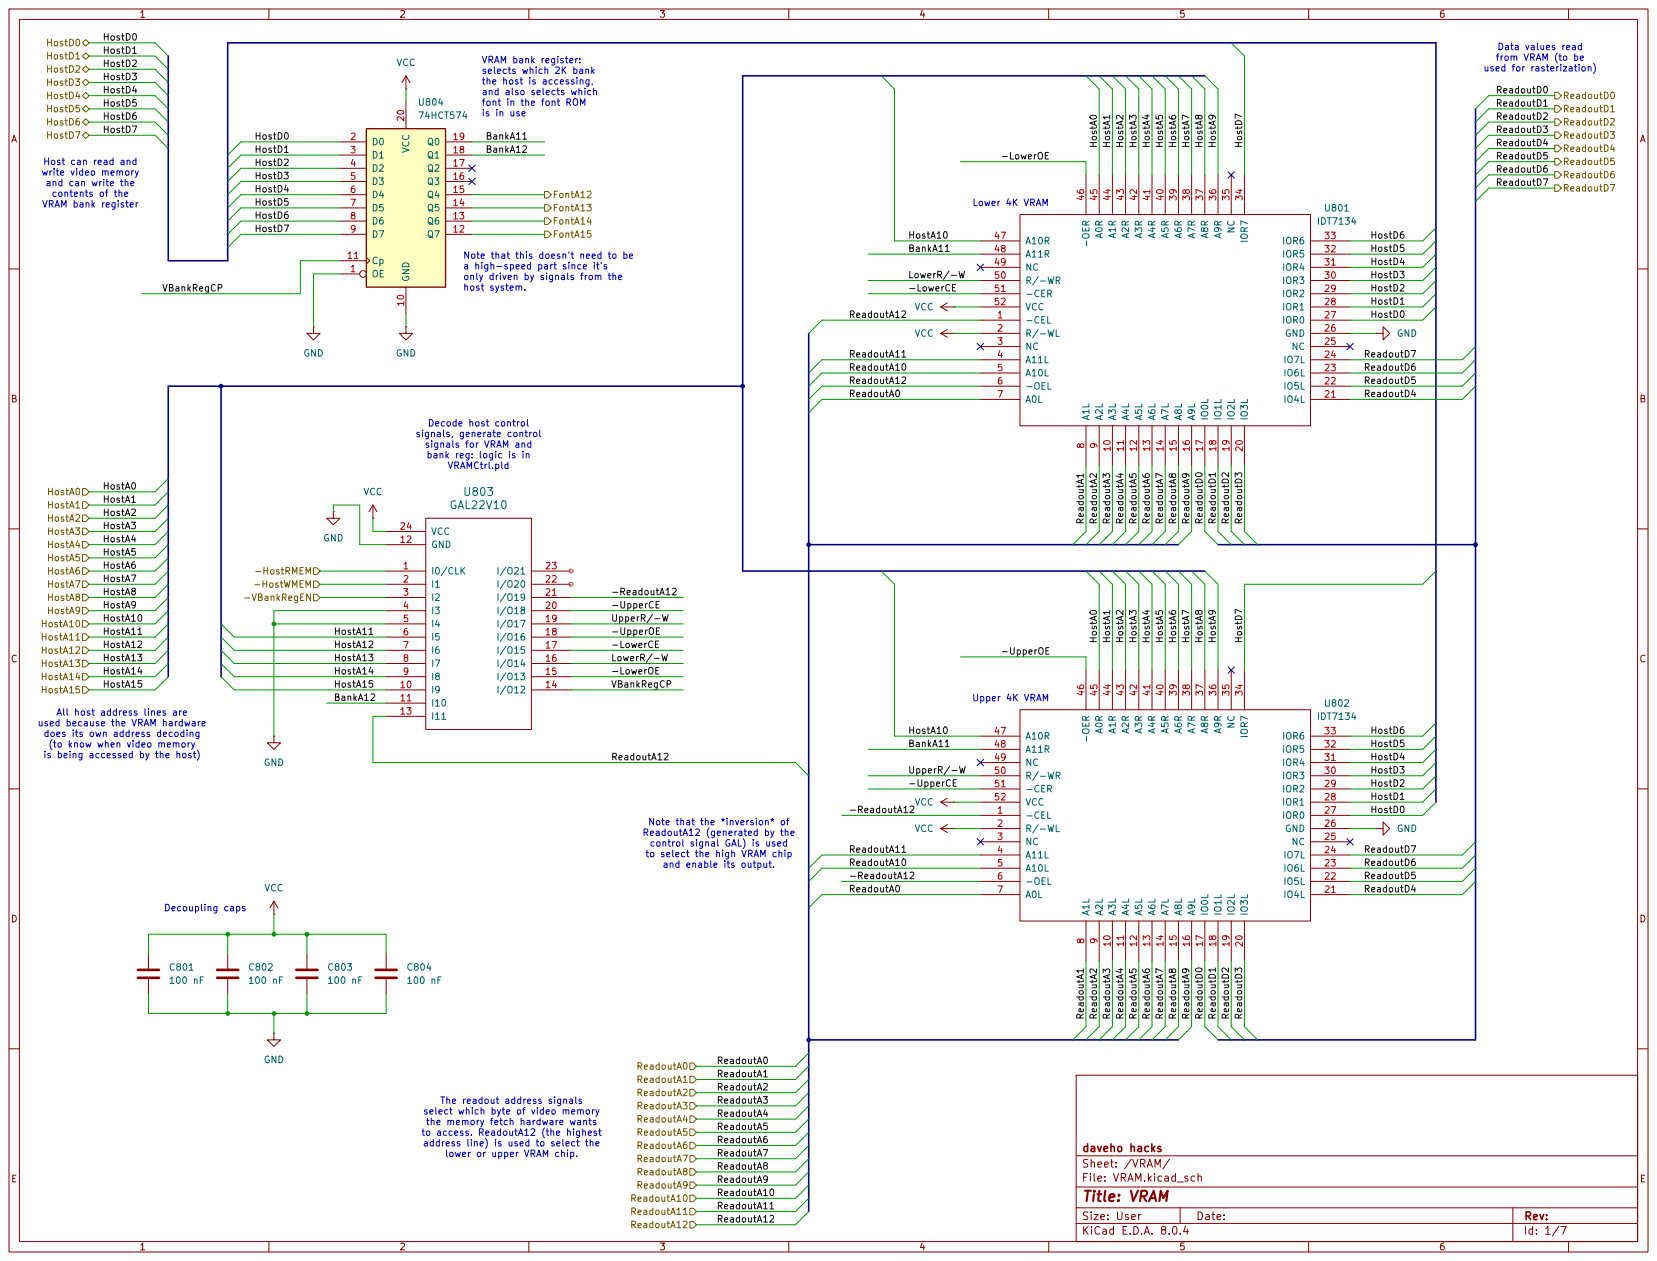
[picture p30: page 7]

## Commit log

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2024-03-07 allow hcount reset when frame ends
    [HCount.kicad_sch, HW_VGA.kicad_sch]
2024-03-08 fix wiring of vcount counters to comparator
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2024-03-12 replace horizontal count logic with GAL22V10
    [HCount.kicad_sch, HW_VGA.kicad_sch]
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2024-03-12 add decoupling caps, fix net labels
    [VCount.kicad_sch]
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2024-03-15 set VCOUNT initially in vertical back porch
    This means that VVis should *not* be asserted
    initially, but should only be asserted once
    the first proper frame begins.
    [HW_VGA.kicad_sch, VCount.kicad_sch]
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2024-03-18 chips driven by GAL or memory need to be 74HCT
    I forgot that GALs only guarantee 2.4V as the minimum
    output high voltage. Bleh.
    [HCount.kicad_sch, Output.kicad_sch, Pixgen.kicad_sch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]
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2024-03-28 use 74ACT parts where needed (e.g., HCount)
    Also, I don't think the 74HCT365 buffer is needed for
    the output DAC. I think a single intensity output can
    feed into all three color outputs. It's a voltage source,
    so it shouldn't really matter what load is on it.
    (Need to test this out in simulation.)
    [HCount.kicad_sch, Output.kicad_sch, VCount.kicad_sch]
2024-05-03 minor tweaks to Output circuit
    The multiplexor definitely needs to be 74ACT.
    Tweaked DAC resistor values to be ones that are more likely
    I actually have. (I don't have any 1.33K, for example.)
    [HCount.kicad_sch, HW_VGA.kicad_sch, Output.kicad_sch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]
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2024-05-11 update Output circuit to use '574 as output reg
    I think it makes sense to have a register for the
    color signal output.
    [HW_VGA.kicad_sch, Output.kicad_sch]
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2024-05-12 use outpt reg for HSync and VSync
    This will ensure that they are generated in sync with
    the color outputs.
    Also, added an output connector for the generated
    VGA signals, and fixed the inputs to the resistor DAC.
    [HW_VGA.kicad_sch, Output.kicad_sch]
2024-05-18 use 27SF512 for char ROM, GAL22V10 for shift reg
    The 27SF512 is the fastest programmable ROM I have,
    at 70 ns, so in theory could produce valid character
    pixel row data after only two clock cycles.
    It's a bit less "authentic" than, let's say, a
    27C256-70, but I don't have any of those, and
    the T48 should be able to program the 27SF512.
    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
    [Pixgen.kicad_sch]
2024-05-19 minor fix to Output module
    [Output.kicad_sch]
2024-05-21 incr VCOUNT only when HCOUNT_END asserted
    As the schematic was drawn originally (and as the
    prototype VCount module was wired originally),
    VCOUNT was incremented on every clock, which
    obviously isn't right.
    Some other misc. cleanups such as specifying
    74ACT163 rather than 74HCT163 for the counters.
    [VCount.kicad_sch]
2024-05-22 fix wiring errors in VCntCtrl simulation
    The inputs to the AND gates generating BeginPulse and
    EndPulse we're driven correctly: an input was unused,
    and one needed VCOUNT signal wasn't connected.
    Also fixed an incorrect comment in VCntCtrl.pld.
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2024-05-25 more work on VRAM host interfacing
    Fixed error in IDT7134 symbol.
    Working on address decoding and lower/upper VRAM
    selection. Since we're using a GAL to decode the host
    control signals, it can just do its own logic to
    recognize when the upper part of the I/O region
    is being accessed. The CPU/glue logic module generates
    -IOR4..-IOR7 signals when this region is accessed,
    but they're not present on the bus. However, the
    control signal decoding GAL can just look at
    A8..A15 to figure out when the VRAM is being
    accessed.
    [VRAM.kicad_sch]
2024-05-25 relative complete VRAM module design?
    Added the interface to the display controller memory
    fetch hardware (is basically just address signals and
    data output.) The readout A12 signal is used to select
    the VRAM device to read from (low or high). The GAL
    inverts this signal for reading from the high VRAM.
    [VRAM.kicad_sch]
2024-05-25 avoid using I/O pin as input on control GAL
    [VRAM.kicad_sch]
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2024-05-27 use upper bits of bank reg to select font
    With 64 KB of font memory, this means that we can
    have 8 different fonts.
    Also cleaned up a few issues in the pixel generator
    module.
    [Pixgen.kicad_sch, VRAM.kicad_sch]
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2024-05-31 VRAM control GAL doesn't need HostA9, HostA10
    Only HostA11..HostA15 are needed to determine which 2KB
    block of host memory is being accessed.
    [VRAM.kicad_sch]
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2024-06-01 reverted previous VCount change; hw was correct
    The TC a.k.a. "RCO" output only goes high if the
    counter is at terminal count, AND the CET input
    is high. Since the low-bit '163 in VCount has its
    CET driven by HCOUNT_END, it only asserts TC/RCO
    if HCOUNT_END is asserted, thus the cascaded counters
    are never enabled if the low counter is not enabled.
    This is good news since it means I don't need to
    change the wiring of the prototype VCount module.
    The change being reverted was not really wrong.
    (I don't think it was wrong anyway.) However, I
    think it's important for the schematics to be
    100% consistent with the prototype hardware.
    [VCount.kicad_sch]
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2024-06-02 more work on Readout module
    Eliminate the 4th 74ACT163 counter managing ReadoutA12:
    we should be able to replace it with a single flip-flop
    in the Readout control GAL.
    Started working on control signals.
    [Readout.kicad_sch]
2024-06-03 update design for accurate VCOUNT during h. vis.
    Rather than incrementing VCOUNT on HCOUNT_END,
    instead increment VCOUNT *early* on HBeginPulse.
    This means that vsync begin and end control pulses
    have their counts increased by 1. Also, VVis
    transitions from 0 back to 1 when VCOUNT is 0
    rather than 524, since VCOUNT gets reset before
    the last scanline of the frame ends.
    This will require a couple of minor hardware changes:
    1. The VCntCtrl GAL will need to generate a VCOUNT_ZERO
    signal (for the transition of VVis back to 1.)
    The VCount module will also need to export this
    signal. However, it will no longer need to export
    VCOUNT_END, which is now only used internally
    within VCntCtrl, so on th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
2024-06-03 revise for accurat VCOUNT mods
    Will need to double check these changes.
    [HW_VGA.kicad_sch, VCount.kicad_sch]
2024-06-04 add backplane connector to main sheet
    Also tidied up a few details related to hardware
    changes needed for accurate VCOUNT during horizontal
    visibility.
    [HW_VGA.kicad_sch, VCount.kicad_sch]
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2024-06-15 limit memfetch+raster by VActive signal
    I think I have the timing of the VActive signal
    somewhat correct: it starts at the correct time,
    when VCOUNT_END is asserted, i.e., just before
    the last (non-visible) scanline of the frame.
    The ReadoutCtrl module does appear to start generating
    the appropriate signals just before the end of the
    last non-visible scanline (in preparation for
    the first visible scanlinen.)
    I'm not sure whether VActive gets turned off at
    the correct time yet. Need to think about this
    (and, of course, run the simulation to see what
    happens.)
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2024-06-19 fixed minor error in Readout module
    One of the unused inputs of the high '273 of the
    row begin address register wasn't tied to ground.
    This still doesn't fix the issue that the row begin
    address isn't loaded from the readout address when
    VCOUNT[0..3] = 15. Will continue to investigate.
2024-06-19 clear row begin address reg on reset
    This should ensure that the first visible frame is
    generated from correct addresses. Not that it really
    matters, since the contents of VRAM will be uninitialized
    at that point.
2024-06-19 update readout schematic with changes from sim
    The simulation seems to be working, so in theory this
    should be a good hardware design.
    [Readout.kicad_sch]
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2024-06-20 more main sheet cleanups
    Also removed one unneeded pin (ReadoutA12) for the
    Readout module: it's a purely internal signal.
    [HW_VGA.kicad_sch, Readout.kicad_sch]
2024-06-20 a few more main sheet cleanups
    At this point I think most/all of the changes to
    the simulation are reflected in the schematic. Need
    to go over everything carefully to make sure.
    [HW_VGA.kicad_sch]
2024-06-20 remove explanatory text about horizontal timing
    ROutCtrl.pld is a more authoritative source of information
    about horizontal timing (and of course the simulation
    as well.)
    [Readout.kicad_sch]
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2024-06-20 fixed some mistakes in Pixgen module
    Some of the character row address labels on nets
    going to the character ROM were wrong.
    [Pixgen.kicad_sch]
2024-06-20 much work on pixel generation schematic, logic
    In theory, this is potentially a complete hardware design,
    but need to simulate it to make sure it will actually work.
    [HW_VGA.kicad_sch, Pixgen.kicad_sch, VRAM.kicad_sch]
2024-06-20 working on simulation of Pixgen module
    One complication is that Logisim Evolution doesn't
    have a model of the '574 register, so I created a
    sub-circuit that I think is equivalent.
2024-06-21 the host needs to write all bits of bank reg
    The high 4 bits of the VRAM bank register are used
    for selecting the font, but this is only possible
    if the bank register's inputs are actually
    connected to the host data bus.
    [VRAM.kicad_sch]
2024-06-22 use enable input of U401 to blank invisible pixels
    This eliminates the need for U402. This change has
    been verified as working using the hard-wired
    prototype.
    Idea suggested by Episode 01 viewer RayBellis:
    thank you, Ray!
    [Output.kicad_sch]
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2024-06-29 more correct rendering of "KiCad"
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2024-06-29 make bank register a 74ACT574
    But, a 74HCT574 should also work, since this is the
    host side, which is far slower than the display
    controller side.
    [VRAM.kicad_sch]
2024-07-06 RowBeginA13..RowBeginA15 are not needed
    There is only 8 KB of VRAM, so only RowBeginA0..RowBeginA12
    are necessary.
    [Readout.kicad_sch]
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2024-07-11 adding missing graphic frame marker
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2024-07-12 more corrections, added frames for schematic
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2024-07-13 map VCOUNT[3:0] to font address bits 3:0
    Each character glyph in the font ROM is stored as 16
    successive bytes representing pixel rows 0-15. Therefore,
    VCOUNT[3:0] should drive the low 4 bits of the font
    address.
    [Pixgen.kicad_sch]
2024-07-13 high bits of attribute are fg, not bg
    There's no particular reason, but this is how it's
    documented in the Episode 03 video, so let's be
    consistent.
    [Pixgen.kicad_sch]
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2024-07-14 fix font ROM address input signals
    I had bits 0-7 connected in reverse previously.
    [Pixgen.kicad_sch]
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2024-07-16 fix attribute register outputs
    [Pixgen.kicad_sch]
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2024-07-16 use 74ALS163 rather than 74ACT163
    The prototype did not work reliably with 74ACT163 counters,
    but did work correctly with 74ALS163 counters.
    [HCount.kicad_sch, Readout.kicad_sch, VCount.kicad_sch]
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2024-07-18 use 74ALS157 instead of 74ACT157
    There is very minor horizontal timing jitter when using the
    74ACT157.
    More generally, I think that aside from the video signal
    output register, which needs to be CMOS in order to generate
    correct VGA color signal voltage levels, all 74ACT parts
    should be 74ALS parts.
    [Output.kicad_sch]
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2024-07-20 use jumper to connect VRefresh to IRQ6
    I'm not 100% certain this feature will work (it doesn't
    on the prototype), so the jumper allows it to be
    selectively enable or disabled.
    [HW_VGA.kicad_sch]
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
